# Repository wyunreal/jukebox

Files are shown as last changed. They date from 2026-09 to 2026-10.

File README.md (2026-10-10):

# jukebox

A homemade jukebox built around a **Raspberry Pi 4B** running
[Volumio](https://volumio.com/): firmware
for power control and input reading (potentiometers, switches and a 4x4 button
matrix) on **Arduino Micro (ATmega32U4)** boards, FreeCAD 3D models of the
hardware (screen, Raspberry Pi, HDD and electronics supports), the audio
software that gives the Pi a custom dual output, and the operations skill used
to run and troubleshoot the box.

## Status

The repository currently contains:

```
firmware/PowerAndPotsArduino/   # PlatformIO project (Arduino Micro)
├── src/main.cpp                # pot/switch reading and serial reporting
├── src/power-state-machine.hpp # relay + short/long press power switch logic
├── platformio.ini
└── README.md                   # detailed firmware documentation

firmware/KeyboardArduino/       # PlatformIO project (Arduino Micro)
├── src/main.cpp                # 4x4 button matrix scan and event reporting
├── platformio.ini
└── README.md                   # detailed firmware documentation

hardware/3d-models/             # FreeCAD models, grouped by part
├── Electronic support/         # PowerAndPots controller board, box, fuse case
├── hdd/                        # hard drive wall support
├── Pi support/                 # Raspberry Pi support
├── screen/                     # screen supports, cover and joints
└── Spectrum/                   # spectrum display frame

software/volumio/              # Volumio flavour (the live box)
├── dual-output/                # custom dual audio output for Volumio
│   ├── deploy.sh / uninstall.sh  # scripts: ship+run over SSH, thin uninstall
│   ├── files/                  # everything that lands on the Pi
│   │   ├── jukebox-audio.sh    # installer / verify / status (engine)
│   │   ├── camilladsp          # CamillaDSP v4.1.3 (armv7), tone-control engine
│   │   ├── libasound_module_pcm_cdsp.so  # cdsp ALSA plugin (armhf, patched)
│   │   ├── cdsp/               # plugin source (patched) + strrep.h
│   │   └── jukebox-audio-guard.* / 89-jukebox-audio.rules  # units + udev rule
│   └── README.md               # design doc: ALSA split, tone, variants, fail-safe
├── pot-overlay/                # on-screen indicator for balance/bass/treble
│   ├── install.sh / uninstall.sh / deploy.sh  # scripts
│   └── files/                  # everything that lands on the Pi
│       ├── jukebox-overlay.py  # dependency-free HTTP/SSE server (port 3210)
│       ├── overlay.js / overlay.css  # UI overlay (reuses Volumio's knob)
│       ├── apply.sh            # (re)inject the loader into the UI pages
│       └── uninject.py         # strip the loader on uninstall
├── ui-nav/                     # daemon -> UI screen navigation channel
│   ├── install.sh / uninstall.sh / deploy.sh  # scripts
│   └── files/                  # everything that lands on the Pi
│       ├── ui-nav.py           # dependency-free HTTP/SSE server (port 3211)
│       ├── ui-nav.js           # injected client; drives the UI's $state
│       ├── apply.sh            # (re)inject the loader into the UI pages
│       └── uninject.py         # strip the loader on uninstall
└── ui-boost/                   # touch UI performance kit for Volumio
    ├── install.sh / uninstall.sh / deploy.sh  # scripts
    └── files/                  # everything that lands on the Pi
        └── jukebox-ui.sh / jukebox-ui-guard.*  # helper + guard units

software/jukebox-pots/          # pot volume/balance/tone from the Arduino
├── install.sh / uninstall.sh / deploy.sh  # scripts
├── files/                      # everything that lands on the Pi
│   ├── jukebox-pots.py         # daemon: USB serial -> DAC volume/balance/tone
│   └── jukebox-pots.service / 89-jukebox-pots.rules / config.env.in
└── README.md                   # design doc: mapping, detection, analyser safety

software/jukebox-keyboard/      # playback keys from the KeyboardArduino
├── install.sh / uninstall.sh / deploy.sh  # scripts
├── files/                      # everything that lands on the Pi
│   ├── jukebox-keyboard.py     # daemon: USB serial -> play/pause/stop/prev/next
│   └── jukebox-keyboard.service / 89-jukebox-keyboard.rules / config.env.in
└── README.md                   # design doc: key map, detection

software/storage/               # host storage: RAID 1 music library
├── raid-music.sh               # set up / adopt the mirror + auto-mount (on-host)
└── README.md                   # design doc: power, UAS quirk, replacing a disk

skills/jukebox/SKILL.md         # agent skill to operate and troubleshoot the box
```

The audio setup splits playback into the I2S DAC (speakers, volume-controlled
by Volumio) and a second constant-level output feeding a hardware spectrum
analyser, with an automatic DAC-only fallback when the second device is absent.
The DAC branch also carries a live **bass/treble tone control** (CamillaDSP),
driven by two of the Arduino's potentiometers — see
[Installing from scratch](#installing-from-scratch).

## Physical controls

Four potentiometers of the PowerAndPots Arduino drive the DAC (speakers) only:

| Pot | Function |
| --- | --- |
| `POT volume` | Volumio volume (0–100 %) |
| `POT balance` | left/right balance of the DAC |
| `POT single` | bass shelf (±8 dB, center = flat) |
| `POT multi second` | treble shelf (±8 dB, center = flat) |

The spectrum analyser feed keeps its constant level and is not affected by any
of them (including the tone). See
[software/jukebox-pots/README.md](software/jukebox-pots/README.md).

## Firmware

- **Power relay** driven by a state machine: short press turns it on, short
  press while on asks the host to shut down (`POWER: soft off`), long press
  (≥ 5 s) performs an immediate hard off; the button acts on release. The relay
  is cut by the Arduino after the Pi has halted (see
  [Power button](software/jukebox-pots/README.md#power-button-soft-power-off)).
- **Serial reporting** (9600 baud, only on change): volume/single/balance/
  multi second pots (with per-segment calibration tables), power tristate,
  power switch, multi push and rotary switch.
- **Button matrix** (4x4, rows on 2-5, columns on 6-9): `DOWN`/`UP` on
  press/release, `PRESS` vs `LONG_PRESS` (1 s threshold) on release and a
  `PRESSED` repeat every 500 ms while held.

Pin map, output format, calibration and flashing: see
[firmware/PowerAndPotsArduino/README.md](firmware/PowerAndPotsArduino/README.md);
button matrix wiring and events: see
[firmware/KeyboardArduino/README.md](firmware/KeyboardArduino/README.md).

## 3D models

FreeCAD (`.FCStd`) models, grouped by part: see
[hardware/3d-models/README.md](hardware/3d-models/README.md).
No STL/STEP exports are committed yet — export from FreeCAD as needed.

## Audio software

Custom dual audio output (I2S DAC + constant-level second output for the
spectrum analyser) with a live bass/treble tone control, for **Volumio**.
Step-by-step, from scratch: see
[Installing from scratch](#installing-from-scratch).

See the full design doc:
[software/volumio/dual-output/README.md](software/volumio/dual-output/README.md)
(engine `files/jukebox-audio.sh`, shipped over SSH by `deploy.sh`).

Physical volume and balance from the PowerAndPots Arduino's potentiometers are
handled by `software/jukebox-pots/` (`jukebox-pots.service`): it reads `POT
volume` / `POT balance` / `POT single` / `POT multi second` over USB serial and
drives the DAC volume, balance and tone, leaving the analyser output untouched.
Install with `software/jukebox-pots/deploy.sh install`; see its
[README](software/jukebox-pots/README.md).

Moving a pot shows an on-screen indicator (a circular knob identical to
Volumio's own volume indicator) for **balance**, **bass** and **treble** — the
latter two are not part of Volumio's state, so `software/volumio/pot-overlay`
adds a small local SSE server that the daemon feeds and the UI renders; see its
[README](software/volumio/pot-overlay/README.md).

## Keyboard (playback keys)

The KeyboardArduino's 4x4 button matrix drives playback. `software/jukebox-keyboard/`
(`jukebox-keyboard.service`) reads its key events over USB serial and runs the
matching Volumio command on key **press**: play, pause, stop, previous track,
next track, mute, clear the queue and save the queue as a playlist. One key
toggles the current track/station in **favourites**, and one can **toggle the
screen** between the now-playing home and the play queue (those two ask the UI,
so they need `software/volumio/ui-nav`). The key → action map is **versioned in
the repo** at `software/jukebox-keyboard/files/keymap.conf` (`ACTION=row,col`) and
installed as-is, so a fresh or re-installed box gets the same keys (a one-off
`--key-action ACTION ROW,COL` overrides single entries). Identify a key with
`--watch`. Install with `software/jukebox-keyboard/deploy.sh install`; see its
[README](software/jukebox-keyboard/README.md).

## Disks & RAID 1 (music library)

The music library lives on **two 3.5" hard drives in USB enclosures, mirrored
(RAID 1)** and mounted where Volumio expects removable storage, so it isn't
capped by the SD card:

| | |
|---|---|
| Array | `/dev/md0`, `raid1`, name `<host>:music` |
| Mount | `/media` — what Volumio's `/mnt/USB` symlinks to, i.e. the **`USB`** source |
| Music | `/media/Music/` (SMB share **`USB`**) |

The set-up/adopt script and the full design notes (power requirements, the
JMicron JMS583 UAS workaround, replacing a failed disk) are in
[software/storage/](software/storage/README.md). From a development machine:

```sh
scp software/storage/raid-music.sh volumio@<host>:/tmp/
ssh volumio@<host> 'echo <password> | sudo -S -p "" \
  bash /tmp/raid-music.sh install --disk-a /dev/sda --disk-b /dev/sdb'
```

It is idempotent and safe: an existing array is only **adopted**, never
reformatted; a non-empty disk is **refused** unless `--reformat` is given.
`verify` / `status` check the array, the mount and the disks.

> **Power matters.** Two 3.5" drives cannot run off the USB bus, and a mirror
> writes to both at once. Without a proper power supply the drives brown out
> under load (USB disconnects, I/O errors, degraded array). These enclosures
> (`152d:0583`) are also unstable with the **UAS** driver, so `install` pins
> `usb-storage.quirks=152d:0583:u` to force Bulk-Only Transport.

## Adding music over the network (SMB)

Volumio already runs Samba (`smbd`/`nmbd`) with **guest** shares, so you don't
need to touch the box at all — just drag files onto it from your computer. The
Pi advertises itself on the LAN under **its own hostname**, so it shows up on its
own under the network neighbourhood / "Network" in your file manager.

### From the file manager (no password)

- **Windows / File Explorer** — open **Network**; the box appears there by
  itself (if it doesn't, type `\\<host>` — or `\\<pi-ip>` — in the address bar).
- **macOS / Finder** — **Go ▸ Connect to Server…** (`⌘K`) and enter
  `smb://<host>` (or `smb://<pi-ip>`).
- **Linux / GNOME Files (Nautilus)** — **Other Locations ▸ smb://<host>**.

| Share | What it is | Where it lands on the Pi |
|---|---|---|
| `Internal Storage` | the SD card: fine for a small library | `/data/INTERNAL` → `Music/` |
| `USB` | the RAID 1 music library (two mirrored HDDs) | `/mnt/USB` → `/media` |
| `NAS` | a staging area for files destined for a NAS | `/mnt/NAS` |

There is **no username or password** (the shares are `guest ok = yes`); connect
as guest/anonymous and open the share you want. For the music library use
**`USB`** and drop the files in its **`Music`** folder (or at the root), i.e.
`USB\Music\...`. The library shows every folder under the MPD music
root, so anything you place in there is indexed.

### From the command line

```sh
# Linux (mount the RAID music library at /mnt/jukebox)
sudo mkdir -p /mnt/jukebox
sudo mount -t cifs '//<host>/USB' /mnt/jukebox \
  -o guest,iocharset=utf8,file_mode=0777,dir_mode=0777
cp -r ~/Music/* /mnt/jukebox/Music/
sudo umount /mnt/jukebox

# macOS
open 'smb://<host>/USB'

# smbclient (guest, one-off copy)
smbclient '//<host>/USB' -N -c 'cd Music; lcd ~/Music; mput *'
```

For a small library you can use the SD card's `Internal Storage` share
(`//<host>/Internal Storage`, `Music/`) instead — the share name has a space,
so quote it.

### After copying: re-scan the library

Volumio's MPD watches its folders but a full (re)scan is the reliable way to
make new files appear. In the web UI: **Browse ▸ My Music ▸ Update** (or
Settings ▸ Sources). The button posts MPD's database update, and from the
command line `mpc` talks to the same daemon:

```sh
mpc update      # incremental: pick up new/changed files
mpc rescan      # full re-read of the whole library
```

> Volumio's REST API does **not** expose `updateLibrary`/`rescan` (the UI uses a
> socket), so `curl '.../api/v1/commands/?cmd=updateLibrary'` answers *command
> not recognized* — use `mpc`, the UI button, or just wait for MPD to notice.
> A file only becomes playable once MPD has it in its database, so if the UI
> lists the file but playback fails or it's missing, run `mpc update`.

## Installing from scratch

Everything below runs from a **development machine** (this repo) and drives the
Pi over SSH. Nothing is hardcoded: pass the host (and a password if you don't
use SSH keys) per command.

Requirements:

* A Raspberry Pi with the I2S DAC (PCM1794A, `sndrpirpidac`) and, for the
  analyser, a USB sound card (`Device`).
* The **PowerAndPots Arduino** flashed
  ([firmware/PowerAndPotsArduino](firmware/PowerAndPotsArduino/README.md)) and
  plugged in (it appears as `/dev/ttyACM0`).
* SSH enabled on the Pi. Either an SSH key or the `-p/--password` option (the
  password is also needed for `sudo` unless it is passwordless).

The order matters: **player first, then the audio chain, then the pots.**

There is also a top-level wrapper that drives all six packages in that order:

```sh
./deploy-all.sh -H user@host install     # every package; second output = usb
./deploy-all.sh -H user@host verify      # run every package's checks
./deploy-all.sh -H user@host status      # show every package's state
./deploy-all.sh -H user@host uninstall   # remove every package (reverse order)
```

The host is **required**: pass `-H/--host user@host` or set `JUKEBOX_HOST`
(there is no built-in default). Use `-p <password>` (or `$JUKEBOX_PASSWORD`) when
`sudo` on the box needs one:

```sh
./deploy-all.sh -H volumio@<host> -p <pass> install
./deploy-all.sh -H volumio@<host> status
```

It just sequences each package's own `deploy.sh`, so the per-package steps below
are the same thing done by hand (and are still the way to pass package-specific
options such as `--key-action`). For this box, `install` fixes the second output
to `usb`. The pot power button (short press halts the Pi) is on by default;
disable it per package with `--no-power-button`:

```sh
# one package at a time (same effect as the orchestrator, with its own flags)
software/volumio/dual-output/deploy.sh  -H volumio@<host> -p <pass> install --second-output usb
software/volumio/ui-boost/deploy.sh     -H volumio@<host> -p <pass> install
software/jukebox-pots/deploy.sh         -H volumio@<host> -p <pass> install --power-off-delay 45
software/volumio/pot-overlay/deploy.sh  -H volumio@<host> -p <pass> install
software/volumio/ui-nav/deploy.sh       -H volumio@<host> -p <pass> install
software/jukebox-keyboard/deploy.sh     -H volumio@<host> -p <pass> install --key-action next 1,4
```

### Volumio (the live box)

1. Flash Volumio and finish its first-run wizard (network, audio output).
   Note the host and the `volumio` user's password.

2. Install the dual output + tone (DAC branch + constant-level USB analyser;
   the tone engine CamillaDSP and the patched `cdsp` plugin are shipped by this
   repo):

   ```sh
   cd software/volumio/dual-output
   ./deploy.sh --host volumio@<host> install --second-output usb
   ```

   Add `--with-playback` to also run the playback check. On a Volumio box the
   installer configures the ALSA split, the MPD buffers, the guard units and
   the CamillaDSP tone step, and ends with a verification table that must say
   **All checks passed**.

3. Install the potentiometer daemon (volume, balance, bass, treble). The pot
   power button (short press halts the Pi, relay cut ~30 s later) is on by
   default; `--no-power-button` / `--power-off-delay N` change that:

   ```sh
   cd software/jukebox-pots
   ./deploy.sh --host volumio@<host> install                       # power button on, 30 s
   ./deploy.sh --host volumio@<host> install --no-power-button     # short press does nothing
   ./deploy.sh --host volumio@<host> install --power-off-delay 45  # cut the relay after 45 s
   ```

   Then, for the on-screen indicator when moving balance/bass/treble pots:

   ```sh
   cd software/volumio/pot-overlay
   ./deploy.sh --host volumio@<host> install
   ```

4. *(Optional)* Speed up the touch UI (GPU compositing, no blur, correct DSI
   resolution):

   ```sh
   cd software/volumio/ui-boost
   ./deploy.sh --host volumio@<host> install
   ./deploy.sh --host volumio@<host> status
   ```

   It takes full effect after a reboot (`ssh volumio@<host> 'sudo reboot'`).

5. *(Optional)* Wire the keyboard's playback keys. The map is versioned in
   `software/jukebox-keyboard/files/keymap.conf`; install it as-is (identify a
   key with `--watch` and edit the file if needed):

   ```sh
   cd software/jukebox-keyboard
   ./deploy.sh --host volumio@<host> install
   ```

   A one-off `--key-action ACTION ROW,COL` (repeatable) overrides single entries
   without touching the repo.

6. **Reboot** so `alsa-restore`, the guard units and the pot daemon come up
   together, then play something and move the four pots.

Verification / state any time (all packages at once, or a single one):

```sh
./deploy-all.sh -H volumio@<host> verify                # every package
./deploy-all.sh -H volumio@<host> status                # every package
./software/volumio/dual-output/deploy.sh --host volumio@<host> verify --with-playback
./software/jukebox-pots/deploy.sh --host volumio@<host> status
```

If `sudo` on the box needs a password, add `-p <password>` or export
`JUKEBOX_PASSWORD=<password>`.

### What each installer does

| Package | What it installs |
|---|---|
| `software/volumio/dual-output` | ALSA split + CamillaDSP tone step + guards + MPD buffers for Volumio |
| `software/volumio/pot-overlay` | On-screen balance/bass/treble indicator (overlay server + injected UI loader) |
| `software/volumio/ui-nav` | UI navigation channel (a daemon can switch the screen; used by the open/close key) |
| `software/jukebox-pots` | `jukebox-pots.service` (volume/balance/tone from the Arduino; power button halts the Pi, on by default) |
| `software/jukebox-keyboard` | `jukebox-keyboard.service` (play/pause/stop/prev/next/mute/clear/save-queue, favourite, open/close the queue view) |
| `software/volumio/ui-boost` | Volumio-only touch UI performance fixes |

## Safety notice

This project drives a power relay (low-voltage control side) and includes
parts meant to be printed and assembled with electronic and electrical
components. In this build the relay switches a PC **ATX power supply**, so the
relay contacts are low voltage — but the PSU still has mains at its input, and
an ATX supply carries high currents and stored energy. Handle it with the usual
care for electrical work; a supply can still get hot or hold a charge. None of
it is a certified or safety-rated design. Use it entirely at your own risk;
if you are not comfortable working with electronics or mains wiring, don't —
consult a professional.

## License

MIT, plus an additional disclaimer of liability and safety notice — see
[LICENSE](LICENSE). The project is provided "as is", with no warranty and no
responsibility for any damage or injury arising from its use.

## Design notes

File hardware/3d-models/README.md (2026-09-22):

# 3D models

FreeCAD models (`.FCStd`) of the jukebox hardware, grouped by part.
Files were made with FreeCAD 1.0 / 1.1 — open with FreeCAD ≥ 1.0.

## Printing

No STL/STEP exports are committed yet — export from FreeCAD
(`File → Export`) and slice as needed.

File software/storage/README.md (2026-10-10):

# storage — RAID 1 music library

Two 3.5" SATA hard drives in USB enclosures, mirrored (**RAID 1**) and mounted
where Volumio expects removable storage, so the music library lives on the
disks instead of the SD card. This directory is **not a package** (no
`deploy.sh` / `install.sh`): it is the on-host script plus this doc. Run it by
hand over SSH.

## What it does

| | |
|---|---|
| Array | `/dev/md0`, `raid1`, name `<host>:music` (so `/dev/md/music`) |
| Filesystem | `ext4`, label `MUSIC` |
| Mount | `/media` — which is what Volumio's `/mnt/USB` symlinks to, so the library shows it as the **`USB`** source |
| Music goes in | `/media/Music/` (SMB share **`USB`**, or `Internal Storage` stays on the SD) |
| Boot | assembled by the `mdadm` udev rules (`/etc/mdadm/mdadm.conf`) and mounted from `/etc/fstab`; the `raid1`/`md_mod` modules are pinned in `/etc/modules-load.d/raid.conf` |

## The important hardware caveats

1. **The disks need their own power supply.** A 3.5" drive needs 12 V + 5 V and
   draws several watts; the USB bus (5 V, 0.5 A) cannot run one, let alone two.
   And a mirror **writes to both disks at once**, so a RAID 1 doubles the power
   draw. Without a proper PSU (the enclosure/dock's barrel jack, or a
   self-powered hub) the drives brown out under load: USB disconnects, I/O
   errors and a quickly-degraded array. This is the number one failure mode.
2. **These enclosures (JMicron JMS583, `152d:0583`) are unstable with UAS.**
   Under load they drop off the bus. The script pins
   `usb-storage.quirks=152d:0583:u` in `/boot/cmdline.txt` to force Bulk-Only
   Transport (`usb-storage`) instead of UAS. It's applied from the next boot.
3. **Watch the negotiated speed.** Some of these adapters report themselves as
   USB 2.0 (`bcdUSB 2.10`) and will never exceed 480 Mbps, however blue the port
   is. ~15–30 MB/s is plenty for playback; it only hurts large copies. If you
   want USB 3.0 speeds, use real USB 3.0 enclosures.

Volumio's root is an overlay on the SD card, so `/etc` changes persist across
reboots — but a **Volumio system update** can reset `/boot/cmdline.txt`, taking
the UAS quirk with it (and the cuelgues come back). Re-run `install` after an
update. The array and its data live on the physical disks and survive anything
done to the SD card.

## Usage (on the Volumio host, as root)

```sh
sudo ./raid-music.sh install                       # create (or adopt) + mount
sudo ./raid-music.sh install --disk-a /dev/sda --disk-b /dev/sdb
sudo ./raid-music.sh install --reformat            # allow wiping non-empty disks
sudo ./raid-music.sh install --resync              # force a full initial resync
sudo ./raid-music.sh install --no-quirk            # don't touch /boot/cmdline.txt
sudo ./raid-music.sh apply                         # re-assert config + mount (idempotent)
sudo ./raid-music.sh verify                        # pass/fail checks
sudo ./raid-music.sh status                        # array, mount, disks, SMART
sudo ./raid-music.sh uninstall                     # remove config, keep the data
sudo ./raid-music.sh uninstall --wipe              # DESTROY the array and its data
```

Safety model:

* If the array already exists it is **adopted** — only `mdadm.conf`, `fstab` and
  the mount are re-asserted. Never reformatted.
* With no array, it uses **two empty whole disks** (auto-detected, or given with
  `--disk-a/--disk-b`). A disk with a partition table or a filesystem is
  **refused** unless `--reformat` is passed.

### From the development machine

```sh
scp software/storage/raid-music.sh volumio@<host>:/tmp/
ssh volumio@<host> 'echo <password> | sudo -S -p "" \
  bash /tmp/raid-music.sh install --disk-a /dev/sda --disk-b /dev/sdb'
```

## Replacing a failed disk

The array keeps serving in degraded mode. To re-add a disk, find the device by
serial and add it; `mdadm` rebuilds the mirror (slow over USB 2.0):

```sh
ls -l /dev/disk/by-id/ata-*                       # find the replacement
sudo mdadm /dev/md0 --add /dev/sdX
watch -n2 cat /proc/mdstat                       # wait for [2/2] [UU]
```

## Recovery

```sh
cat /proc/mdstat
sudo mdadm --detail /dev/md0
sudo ./raid-music.sh verify
dmesg | grep -iE 'usb|uas|I/O error|reset'       # link problems live here
```

If both disks vanish, it's almost always power or the USB link, not the disks —
check the PSU and the enclosure before touching the array.

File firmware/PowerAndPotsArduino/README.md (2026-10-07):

# PowerAndPotsArduino

Firmware for the jukebox's **Arduino Micro (ATmega32U4)**: drives the power
relay through a power switch state machine and reports the state of
potentiometers and switches over USB serial (9600 baud).

## Power switch state machine (`src/power-state-machine.hpp`)

The relay starts **OFF** when the Arduino powers up. All turn-on actions
happen **on button release**:

| Relay state | Press | Action |
|---|---|---|
| OFF | short or long (any) | on release: relay **ON** + `POWER: ON` |
| ON | short (< 5 s) | on release: `POWER: soft off` (relay stays on) |
| ON | long (≥ 5 s) | at 5 s, while still held: `POWER: hard off` + relay **OFF** immediately (the later release is ignored) |

The long-press threshold lives in `POWER_LONG_PRESS_MS` (5000 ms).

### Soft off → the host powers itself down

`POWER: soft off` is a *request*, not an action: the host (the Raspberry Pi)
turns it into a clean shutdown. The **jukebox-pots** daemon watches for that
line and, when the power button is enabled, powers the Pi off and tells this
board to cut the relay **afterwards**:

```
button short press --> POWER: soft off --> Pi: systemctl poweroff
                                      \-> "POWER: off 30" --> relay OFF in 30 s
```

The relay must stay on while the Pi halts, and the Pi cannot send anything once
it is down — but this board keeps running from 5VSB — so the **delay lives
here**. On `POWER: off [N]` the firmware arms a cut `POWER_OFF_DELAY_MS`
(default 30000 ms) later; the optional `N` (seconds, may be `0`) overrides it,
so the host can tune the delay without reflashing. The cut prints
`POWER: hard off` when it happens. A **long press** still cuts immediately and
cancels any pending cut (`POWER: off cancelled`), which is also the escape
hatch if the Pi hangs and never shuts down.

> A second short press after the Pi has halted re-turns the relay on
> (`POWER: ON`) without booting anything, because the Pi is down. Use the long
> press to cut cleanly.

## Serial report

Output over USB at 9600 baud. Values are only reported when they change,
at most every 250 ms (`REPORT_INTERVAL_MS`). A `-----` separator is printed
whenever anything is reported.

**Status request.** Send a newline (or any line that does not start with
`POWER:`) and the firmware re-emits every value once, even if none changed. The
host uses this right after opening the port (`jukebox-pots` writes a newline) so
it can seed the volume and balance from the current pot positions — needed
because the board may already be running (powered from 5VSB) when the Pi boots
and would otherwise stay silent.

**Host commands.** A line beginning with `POWER:` is a command instead of a
status request (the line ends at `\n`/`\r`):

| Line from the host | Effect |
|---|---|
| `POWER: off` | arm a relay cut after `POWER_OFF_DELAY_MS` (30 s) |
| `POWER: off N` | same, but cut after `N` seconds (may be `0`) |
| `POWER: cancel` | disarm a pending cut (host could not shut down) |

Any other input (including a lone newline) is the full status request above.

```
POT volume: 15 (raw 700)
POT single: 20 (raw 1020)
POT balance: 10 (raw 512)
POT multi second: 0 (raw 540)
POT aux: 12 (raw 640)
POWER tristate: CENTER|LEFT|RIGHT
POWER switch: ON|OFF
MULTI PUSH switch: ON|OFF
MULTI ROTARY switch: OFF|SW1|SW2
-----------------------------------------
```

Potentiometers are scaled through per-segment calibration tables
(`POT_VOLUME_POINTS`, `POT_SINGLE_POINTS`, `POT_BALANCE_POINTS`,
`POT_MULTI_SECOND_POINTS`, `POT_AUX_POINTS` in `src/main.cpp`): each entry maps
a raw reading to a value, interpolating between points. Adjust them there to
calibrate your hardware.

## Multiplexer

The Pro Micro only breaks out A0-A3 and all four are used, so extra pots go
through a **CD4051B** 8:1 analog mux whose common output feeds `A0`. Address
bits (C tied to GND; `INH` and `VEE` to GND):

| A (D7) | B (D5) | Channel | Pin | Pot |
|---|---|---|---|---|
| 0 | 0 | X0 | 13 | multi second |
| 1 | 0 | X1 | 14 | balance |
| 0 | 1 | X2 | 15 | **aux** (spare) |
| 1 | 1 | X3 | 12 | spare |

The firmware reads the three channels in turn each loop by setting A
(`MUX_SELECT_PIN`) and B (`MUX_SELECT2_PIN`). To add a fourth pot, wire the next
channel to a free mux input and add its read (with a `PotPoint` table and a
`ReportedValue`) in the same block.

## USB identification

The jukebox also carries a KeyboardArduino; both are identical Arduino Micros
(same VID:PID, no unique USB serial). To let the host tell them apart without
depending on which USB port each is plugged into, this firmware sets
`board_build.usb_product = Jukebox Pots` in `platformio.ini`, so the board
enumerates with the product string **"Jukebox Pots"** (and appears as
`/dev/serial/by-id/usb-Jukebox_Pots_*-if00`). The keyboard board sets its own
string. `jukebox-pots` selects the port by this string.

## Pin map

| Pin | Function | Notes |
|---|---|---|
| 2 | Power relay | **active-low** module (`RELAY_ON = LOW`), defined in `power-state-machine.hpp` |
| 14 | Power switch | `INPUT`, HIGH = pressed |
| 15 | Single pot supply | enabled only during its reading |
| A0 | Mux analog input | |
| 7 | Mux address A | LOW = multi second pot, HIGH = balance pot |
| 5 | Mux address B | LOW = X0/X1, HIGH = X2 aux pot (see above) |
| A1 | Volume pot | |
| A2 | Power tristate pot | raw > 500 → RIGHT, > 100 → LEFT, else CENTER |
| A3 | Single pot | |
| 4 | Multi push switch | `INPUT_PULLUP`, active LOW (ON = pressed) |
| 8, 9 | Rotary switch 1/2 | `INPUT_PULLUP`, active LOW |

## Build and flash

[PlatformIO](https://platformio.org/) project:

```sh
pio run                # build
pio run -t upload      # flash
pio device monitor     # serial monitor (9600)
```

On Linux, install the udev rules so the Micro's port is accessible
without root:

```sh
sudo cp 99-platformio-udev.rules /etc/udev/rules.d/
sudo udevadm control --reload-rules && sudo udevadm trigger
```

`99-platformio-udev.rules` is PlatformIO's standard file (Apache 2.0).

## Layout

```
src/main.cpp                  # pot/switch reading and serial reporting
src/power-state-machine.hpp   # relay + short/long press power switch logic
99-platformio-udev.rules      # PlatformIO udev rules (Linux)
```

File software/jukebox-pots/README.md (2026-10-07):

# jukebox pots (volume + balance + tone from the Arduino)

Turns four potentiometers of the **PowerAndPotsArduino** into physical
controls **for the speakers (I2S DAC) only**: volume, balance, bass and
treble.

The Arduino prints their state on its USB serial port (9600 baud, only on
change):

```
POT volume: 15 (raw 700)
POT balance: 10 (raw 512)
POT single: 12 (raw 640)
POT multi second: 8 (raw 430)
POT aux: 18 (raw 900)
POWER switch: ON
```

The Arduino also reports its power button (`POWER: soft off` on a short press,
`POWER: hard off` on a long one); the daemon can turn that into a clean Pi
shutdown — see [Power button](#power-button-soft-power-off).

A small daemon reads those lines and applies them to the DAC branch of the
chain, on the **Volumio** box:

| Pot | Range | Effect |
| --- | --- | --- |
| `POT volume` | 0–20 | Volumio volume ceiling, 0–100 % |
| `POT aux` | 0–20, 20 = full | **auxiliary volume**: attenuates the ceiling, 0 = silence |
| `POT balance` | 0–20, center 10 | pan of the DAC left/right (opposite channel attenuated) |
| `POT single` | 0–20, center 10 | **bass** shelf, ±8 dB |
| `POT multi second` | 0–20, center 10 | **treble** shelf, ±8 dB |

The two volume pots **multiply**: the volume pot sets the system ceiling and
the aux pot scales it down. The value sent to the player is
`volume_pot × (aux / 20)`, so the aux never exceeds the ceiling and reaches
silence at 0:

| `POT volume` | `POT aux` | Volumio |
| --- | --- | --- |
| 20 (100 %) | 20 | 100 % |
| 20 (100 %) | 10 | 50 % |
| 10 (50 %) | 20 | 50 % |
| 10 (50 %) | 10 | 25 % |
| 20 (100 %) | 0 | 0 % (silence) |

Both are re-applied whenever either pot moves. Older firmware without the
`POT aux` line still works: the aux then defaults to full.

Center (10) on either tone pot means **0 dB**, i.e. bit-for-bit transparent.
The pots are not hard-wired to a function: `JP_TONE_BASS_POT` and
`JP_TONE_TREBLE_POT` pick which firmware lines drive bass and treble
(`single` / `multisecond` by default).

The **second, constant-level output that feeds the spectrum analyser is never
touched**: volume lives on the DAC branch only and the tone shelves live on the
DAC branch only, so nothing in this package can change its level or response.

## How it works

```
PowerAndPotsArduino --USB serial--> jukebox-pots daemon
                                      | volume  -> player volume (DAC branch)
                                      | balance -> DAC pan (per-channel)
                                      '- tone    -> CamillaDSP config + SIGHUP (live)
```

The volume path, balance and tone are those of the **Volumio** chain:

| | Volumio |
| --- | --- |
| Volume | Volumio API (`/api/v1/commands/?cmd=volume`) -> `SoftMaster` |
| Balance | two channels of `SoftMaster Playback Volume` |
| Tone | shelves in `/usr/local/jukebox-audio/cdsp/camilla.*.yml` |

* **Volume** goes through Volumio's own volume path, so the UI/API stay in
  sync, and is the product of the volume pot (ceiling) and the aux pot
  (attenuation). If the API is unreachable the daemon writes the ALSA mixer
  directly instead.
* **Balance** attenuates the channel opposite to the pan, keeping the other at
  its current level via the left/right values of `SoftMaster`.
* **Bass/treble** rewrite the two shelf `gain:` values in the CamillaDSP
  config and send the running process a `SIGHUP`; it re-reads the config and
  rebuilds the filters **without interrupting playback**. The rewrite finds
  the shelves by their biquad type (`Lowshelf`/`Highshelf`) and preserves the
  file's mode/owner so MPD's `cdsp` plugin can keep rewriting it.
* The daemon has **no third-party dependencies** (no `pyserial`); it opens the
  serial port with `termios` and re-scans for it when missing, so it survives
  the Arduino being unplugged/replugged. A udev rule also restarts it when a
  `ttyACM`/`ttyUSB` appears.
* Right after opening the port the daemon **requests a full status report** (it
  writes one byte; the firmware re-emits every value). This is required at boot:
  the board is powered from 5VSB and may already be running when the Pi comes
  up, and the firmware only reports on change, so without the request the daemon
  would never learn the current pot positions and volume/balance would not be
  seeded.
* The daemon never asserts DTR (see the clone notes above); the firmware reports
  regardless of it, and the status request is a plain byte.

## Power button (soft power off)

The PowerAndPots Arduino runs the board's power state machine, so its button is
the jukebox's power button. A **short press** prints `POWER: soft off` and
leaves the relay on; a **long press** (≥ 5 s) cuts the relay immediately.

With the power button enabled (the default), the daemon turns that short press
into a clean shutdown of the Pi:

```
button short press --> Arduino "POWER: soft off"
                   --> daemon: send "POWER: off 30" to the Arduino
                   --> daemon: systemctl poweroff
                   --> Arduino waits 30 s, then cuts the power relay
```

The relay must stay on until the Pi has finished halting, and the Pi cannot
send anything once it is down. The board, however, keeps running from 5VSB, so
the **delay lives there**: the daemon arms it in the last message it sends
(`POWER: off <delay>`), the firmware counts down and cuts the relay. The delay
is `--power-off-delay` / `JP_POWER_OFF_DELAY_S` (**default 30 s**, choose your
own margin for how long the Pi really takes to halt). The **long press** stays
the immediate hard cut, and cancels any pending cut — the escape hatch if the
Pi hangs.

This is **on by default**; it is irreversible: once the Pi is down, software
cannot bring it back. Disable it with `--no-power-button` (or
`JP_POWER_BUTTON=0`). `--power-cmd "CMD"` overrides the halt command (default
`systemctl poweroff`); the daemon runs as root. Inspect the sequence without
touching anything with:

```sh
sudo /usr/local/jukebox-pots/jukebox-pots.py --poweroff-test
```

> The daemon must not assert DTR (see the DTR note above): it reboots the board,
> which resets the relay and would drop power. Nothing here does.

## Install

From this directory (the script copies itself to the Pi and runs it there):

```sh
./deploy.sh install
```

Or directly on the host (Volumio):

```sh
sudo ./install.sh install
```

Common option examples (all flags are also in the table below):

```sh
./deploy.sh install                              # power button ON, relay cut 30 s after
./deploy.sh install --no-power-button            # short press does nothing
./deploy.sh install --power-off-delay 45         # wait 45 s before cutting the relay
./deploy.sh install --power-cmd 'shutdown -h now'
```

The installer is **idempotent**: re-running it just re-asserts the same files
and restarts the service. It will:

1. detect the I2S DAC card (`sndrpirpidac`) unless `--dac-card` is given,
2. install the daemon in `/usr/local/jukebox-pots/`,
3. install and enable `jukebox-pots.service` (starts at boot, stays up,
   `Restart=always`),
4. install a udev rule that restarts the service when the serial port appears.

## Verify / operate

```sh
./deploy.sh status
./deploy.sh verify
./deploy.sh uninstall
```

* `status` shows the detected port, its USB product string and the current
  `SoftMaster` Left/Right values.
* `verify` checks the daemon, the self-tests, the unit state, the serial port
  and the `SoftMaster` control.
* The daemon can be probed on its own:

  ```sh
  sudo /usr/local/jukebox-pots/jukebox-pots.py --probe    # port + mixer + a few lines
  sudo /usr/local/jukebox-pots/jukebox-pots.py --selftest # mapping tests
  ```

## Identify the Arduino

The jukebox has **two identical Arduino Micros** (the PowerAndPots one and the
keyboard one). They share the USB VID:PID `2341:8037` and carry **no unique USB
serial number**, so the kernel cannot tell them apart by id — and binding the
daemon to a port number or a `by-path` link would break as soon as a cable or
hub moved. Instead each board is flashed with its own **USB product string**:

| Board | `board_build.usb_product` | `/dev/serial/by-id` link |
| --- | --- | --- |
| PowerAndPots | `Jukebox Pots` | `usb-Jukebox_Pots_*-if00` |
| Keyboard | `Jukebox Keyboard` | `usb-Jukebox_Keyboard_*-if00` |

The daemon selects the board whose product string is `Jukebox Pots`
(`--product` / `JP_PRODUCT` to change it, must match the firmware). Lookup
order:

1. `--port DEV` / `JP_PORT` if you set one explicitly;
2. a `/dev/serial/by-id/*` symlink whose name matches the product string;
3. any `/dev/ttyACM*` / `/dev/ttyUSB*` whose sysfs `product` matches.

> If `lsusb` does not show the board at all, it is usually a **charge-only USB
> cable** or a port without data lines. Try another cable before anything else.

### Powering the board from 5VSB (VBUS sense)

On the ATmega32U4 the **VBUS pin is not only power — it is the "a USB host is
present" signal**. The chip only talks USB when it sees ~5 V there.

Feeding 5VSB into the Arduino **`5V` pin** is fine and, on a genuine Arduino
Micro, *also* satisfies VBUS: its power-select FET (T1) connects `5V` to the
VUSB net whenever VIN is low, so the 5 V also reaches the VBUS sense input. The
usual cable with the **VBUS wire cut** (D+/D-/GND only) then has no path back to
the Pi, so there is no back-feed either.

* VBUS cut + 5 V into `5V` (Micro) -> sense OK, enumerates, no back-feed.
* VBUS intact + 5 V into `5V` -> works, but 5VSB can push ~150 mA back into the
  Pi's USB port through T1 + the polyfuse; put a Schottky in the VBUS wire
  (cathode towards the Arduino) if you keep the cable whole.

**Clone warning (e.g. Pro Micro).** The clones have no T1, so feeding their `5V`
/ `VCC` pin does **not** put anything on VBUS sense: the board is powered (LEDs
on) but **never enumerates** — `lsusb` stays empty and `dmesg` shows no attempt
at all. The fix is to tie the supply to VBUS sense:

* bridge the **`J1`/`SJ1` solder jumper** (present on the Pro Micro, next to the
  USB connector) — its one pad is VCC and the other is UVCC/VBUS. On a 5 V board
  it is meant to be closed; or
* solder a wire from the `5V`/`VCC` pin to the VBUS net (the USB-C VBUS pins
  A4/A9/B4/B9, or the polyfuse `F1` beside the connector).

Measure to confirm: with 5VSB on and **no USB cable**, the VBUS net must read
~5 V. Then the board appears as `2341:8037` on `/dev/ttyACM0` within a second or
two of the Pi's USB becoming active.

### DTR resets the board (and the power relay)

The daemon deliberately **does not assert DTR**. On the Arduino Micro DTR is
wired to reset, and this board also runs the power-button state machine: raising
DTR reboots it, which resets the relay state and would cut power if the jukebox
is running. The firmware streams regardless of DTR, so plain `termios` suffices.

## Options

| Option | Default | Meaning |
| --- | --- | --- |
| `--dac-card NAME` | auto | ALSA card id of the DAC |
| `--port DEV` | auto | serial device (overrides product matching) |
| `--product STR` | `Jukebox Pots` | USB product string of the PowerAndPots board |
| `--baud N` | 9600 | serial baud rate |
| `--pot-max N` | 20 | firmware pot range |
| `--volume-max N` | 100 | player volume scale |
| `--balance-center N` | 10 | pot value meaning "centered" |
| `--balance-span N` | 10 | pot steps from center to hard pan |
| `--volume-invert` | off | reverse the volume pot direction |
| `--balance-invert` | off | reverse left/right |
| `--no-api` | off | write the mixer directly instead of the player volume path |
| `--tone` / `--no-tone` | on | enable/disable the bass+treble pots |
| `--tone-max-db N` | 8 | shelf range at the pot extremes |
| `--tone-center N` | 10 | pot value meaning "flat" |
| `--tone-span N` | 10 | pot steps from center to full shelf |
| `--tone-bass-pot NAME` | single | firmware line driving bass (`single`/`multisecond`) |
| `--tone-treble-pot NAME` | multisecond | firmware line driving treble |
| `--tone-bass-invert` | off | reverse the bass pot direction |
| `--tone-treble-invert` | off | reverse the treble pot direction |
| `--power-button` / `--no-power-button` | on | short power-button press halts the Pi |
| `--power-off-delay N` | 30 | seconds the Arduino waits before cutting the relay |
| `--power-cmd CMD` | `systemctl poweroff` | command used to halt the Pi |

The same values can be set as environment variables in
`/usr/local/jukebox-pots/config.env` (`JP_*`), which the unit loads at start.

## Notes

* The firmware already scales the raw ADC reading, so the daemon consumes the
  `POT volume` / `POT balance` / `POT single` / `POT multi second` values
  directly. If you re-calibrate the pots in the firmware, the daemon needs no
  change.
* `SoftMaster` is created by the `softvol` plugin the first time the chain is
  opened. The daemon creates it on demand (a 1-second silent `aplay`) if it is
  missing, and the standard `jukebox-audio` install materializes it too.
* Balance is relative to the current level, so it keeps working across volume
  changes; only the two channel values of `SoftMaster` are written.
* The tone pots only work when the dual-output package was installed with the
  tone enabled (the default). Gains are applied live with a `SIGHUP` on
  `/usr/local/jukebox-audio/cdsp/`; the template is updated too, so the
  setting survives a regeneration by the guard and a reboot.
* The daemon never asserts DTR (see the hardware notes above); the firmware
  reports regardless of it, and the status request is a plain byte.
* Uninstall removes the service, the unit, the udev rule and
  `/usr/local/jukebox-pots/`, and restores nothing else — the audio chain was
  never modified by this package.

## Layout

```
install.sh            # idempotent installer (install/verify/status)
uninstall.sh          # remove the service, unit, udev rule and files
deploy.sh             # ship and run install.sh/uninstall.sh over SSH
files/                # everything that lands on the host (readable, human)
├── jukebox-pots.py   # the daemon (+ --probe and --selftest)
├── jukebox-pots.service
├── 89-jukebox-pots.rules
└── config.env.in     # settings template (@PLACEHOLDER@ filled at install)
README.md             # this file
```

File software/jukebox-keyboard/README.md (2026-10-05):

# jukebox keyboard (playback keys)

Turns the **KeyboardArduino** (a 4x4 button matrix) into playback transport
controls for the jukebox: play, pause, stop, previous track and next track.

The board reports key events over USB serial (9600 baud, `<EVENT> <row> <col>`,
1-based). A small daemon reads them and runs the matching Volumio command, so
pressing a key acts immediately (`DOWN` / `on key press`).

It finds its board the same way as `jukebox-pots`: by the **USB product string**
baked into the firmware (`board_build.usb_product = Jukebox Keyboard`), never by
USB port. The two Arduino Micros are identical, so the port would not be stable.

## Layout

```
install.sh             # installer / verify / status
uninstall.sh           # remove the service, unit, udev rule and files
deploy.sh              # ship and run install.sh/uninstall.sh over SSH
files/                 # everything that lands on the host (readable, human)
├── jukebox-keyboard.py
├── jukebox-keyboard.service
├── 89-jukebox-keyboard.rules
├── keymap.conf        # the key map (source of truth: ACTION=ROW,COL)
└── config.env.in      # settings template; keymap.conf fills the key map (@PLACEHOLDER@)
README.md
```

Favourite and the open/close screen toggle are not Volumio commands: the daemon
asks the UI to do them (via `software/volumio/ui-nav`), so the UI updates itself
(heart, toast, routing). Everything else runs the Volumio API directly.

## Configuration

The key -> action map is **versioned in the repo** at
`software/jukebox-keyboard/files/keymap.conf` (`ACTION=ROW,COL`, 1-based, one per
line). `install.sh` installs it as `/usr/local/jukebox-keyboard/config.env`, so a
fresh box (or a re-install) gets exactly the map in the repo. Edit `keymap.conf`
and re-run the installer to change it; a one-off `--key-action ACTION ROW,COL`
on the command line overrides a single entry for that run.

Actions:

| Action | Volumio command |
|---|---|
| `PLAY` | `cmd=play` |
| `PAUSE` | `cmd=pause` |
| `STOP` | `cmd=stop` |
| `CLEAR` | `cmd=clearQueue` (empties the play queue) |
| `PREV` | `cmd=prev` |
| `NEXT` | `cmd=next` |
| `MUTE` | toggles mute (reads the current state, then mute/unmute) |
| `OPENCLOSE` | toggles the UI between the now-playing home and the play queue |
| `FAVOURITE` | toggles the current track/station in favourites (music uses Volumio's own path; radios are handled by `ui-nav`, see below) |
| `SAVEQUEUE` | saves the current queue as a playlist, auto-named `Playlist N` (asks `ui-nav` for the next free name) |

`FAVOURITE` runs through the UI (`software/volumio/ui-nav`), so the heart and
the toast update. For **webradio** this is not just cosmetic: Volumio's backend
has a gap (its `checkFavourites` only looks at the music favourites list), so
its own heart never lights for a radio and its add never toggles. `ui-nav` fills
that in for radios only.

`OPENCLOSE` is not a Volumio command: it asks the UI to switch view, so it needs
`software/volumio/ui-nav` installed (its server is the daemon → UI channel, and
its injected client calls the UI's `$state`).

## Identify the keys

The board prints `DOWN r c` on press, `UP r c` on release and `PRESS r c` /
`LONG_PRESS r c` on release as a classification. To find a key's coordinates,
watch the port and press it:

```sh
sudo /usr/local/jukebox-keyboard/jukebox-keyboard.py --probe
# or watch live:
sudo /usr/local/jukebox-keyboard/jukebox-keyboard.py --watch
```

## Install

```sh
./deploy.sh --host volumio@<host> install
```

The key map comes from `files/keymap.conf`; `--key-action ACTION ROW,COL`
(repeatable) overrides single entries for a one-off run.

The overlay/UI packages are independent; this one only needs the keyboard board
flashed with its own USB product string.

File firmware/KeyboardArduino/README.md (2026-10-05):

# KeyboardArduino

Firmware for the jukebox's **Arduino Micro (ATmega32U4)**: scans a 4x4
push-button matrix and reports press events over USB serial (9600 baud).

## Button matrix

16 plain push buttons wired as a 4x4 matrix — no external resistors or
diodes needed: rows are driven outputs and columns use the internal
pull-ups (`INPUT_PULLUP`).

| Pins | Function |
|---|---|
| 2-5 | Rows (outputs, one driven LOW at a time) |
| 6-9 | Columns (`INPUT_PULLUP`, LOW = pressed) |

Without diodes, three buttons pressed at once forming a rectangle can
produce a ghost key; single presses are unaffected.

## Serial events

Output over USB at 9600 baud, format `<EVENT> <row> <col>` with 1-based
row/column numbering:

| Event | Meaning |
|---|---|
| `DOWN 2 3` | button pressed |
| `UP 2 3` | button released |
| `PRESS 2 3` | short press: released after less than `LONG_PRESS_MS` (1000 ms) |
| `LONG_PRESS 2 3` | long press: released after `LONG_PRESS_MS` (1000 ms) or more |
| `PRESSED 2 3` | repeat, emitted every `REPEAT_MS` (500 ms) while held |

Example (short press of row 1, column 2):

```
DOWN 1 2
PRESSED 1 2
UP 1 2
PRESS 1 2
```

Debounce is `DEBOUNCE_MS` (20 ms); all constants live at the top of
`src/main.cpp`.

## USB identification

This board is an Arduino Micro identical to the PowerAndPots one (same VID:PID,
no unique USB serial). `platformio.ini` sets
`board_build.usb_product = Jukebox Keyboard`, so it enumerates with the product
string **"Jukebox Keyboard"** (`/dev/serial/by-id/usb-Jukebox_Keyboard_*-if00`),
which lets the host address it independently of the USB port.

## Build and flash

[PlatformIO](https://platformio.org/) project:

```sh
pio run                # build
pio run -t upload      # flash
pio device monitor     # serial monitor (9600)
```

On Linux, install the udev rules so the Micro's port is accessible
without root:

```sh
sudo cp 99-platformio-udev.rules /etc/udev/rules.d/
sudo udevadm control --reload-rules && sudo udevadm trigger
```

`99-platformio-udev.rules` is PlatformIO's standard file (Apache 2.0).

## Layout

```
src/main.cpp                  # matrix scan, debounce and event reporting
99-platformio-udev.rules      # PlatformIO udev rules (Linux)
```

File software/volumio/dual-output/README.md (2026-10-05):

# jukebox dual output (Volumio + Raspberry Pi)

Adds a second, **constant-level** audio output while keeping the I2S DAC as
the main, volume-controlled output, plus a **bass/treble tone control** on the
speaker path.

What you get:

| Output | Level | Tone control |
| --- | --- | --- |
| I2S DAC (speakers) | controlled by the normal Volumio volume slider / API / MPD | **bass + treble** (CamillaDSP) |
| Second output (spectrum analyser) | constant level; not affected by volume | none (stays untouched) |

Both outputs always play the same stream, simultaneously.

## Tone control (bass / treble)

The DAC branch carries a low-shelf and a high-shelf biquad, applied by
[CamillaDSP](https://github.com/HEnquist/camilladsp) through the ALSA `cdsp`
plugin (shipped precompiled in this directory, source + `strrep.h` in `cdsp/`).

```
volumio -> softvolume -> jukeboxRoute -> jukeboxSplit (multi)
    |- volumioSoftVol (SoftMaster: volume/balance)
    |      '- jukeboxTone (cdsp -> CamillaDSP: Lowshelf + Highshelf) -> DAC
    '- jukeboxEq (analyser bass trim) -> USB/HDMI/jack  (analyser)
```

* Both shelves default to **0.0 dB**, which is bit-for-bit transparent.
* `jukebox-pots` rewrites the two gains in the CamillaDSP config and sends it
  a `SIGHUP`, so the tone changes **live**, without stopping playback.
* The tone applies to the **DAC branch only**; the analyser feed is not
  affected by the tone (by design).
* CamillaDSP runs at the file's native rate (the `cdsp` plugin substitutes
  `$samplerate$`/`$format$`/`$channels$` on every open), so hi-res files are
  not resampled.
* `chunksize` is **512** on purpose: a larger chunk than the plugin's pipe
  buffer deadlocks the stream (the player waits forever in `poll()`); 512
  matches it.
* Tone options: `--no-tone` (`JB_TONE=off`), `--tone-bass HZ`,
  `--tone-treble HZ`, `--tone-q Q`. Rebuild the plugin on the host with
  `JB_TONE_BUILD_CDSP=1` (needs `gcc` + `libasound2-dev`).

## Choosing the second output

| `--second-output` | Device | Notes |
| --- | --- | --- |
| `usb` | a **USB sound card / DAC** (any extra ALSA card) | **Recommended.** Independent device, no interference with display or jack. |
| `hdmi` | an **HDMI audio extractor** | Digital end-to-end (no PWM noise), but on this Pi it can grab the DSI touch screen as a DRM output and disable the touch_display plugin. Test before adopting. |
| `jack` | the Pi **3.5 mm jack** | Simple, but the jack is a PWM output prone to conducted noise (fixed pattern visible in an analyser). |
| `none` | — | Only the DAC plays (no second output). |

The installer auto-detects the cards; if the chosen second output is not
present at install time (e.g. USB unplugged), it installs a **DAC-only
fallback** and switches to the full dual chain automatically when the device
appears (udev handles hotplug).

## Install

From this directory (the deploy wrapper copies the package — scripts, the
engine and its binaries under `files/` — to the Pi and runs it there):

```sh
./deploy.sh install --second-output usb     # or: hdmi / jack / none
```

Or directly on the Volumio host (run the engine inside `files/`):

```sh
sudo ./files/jukebox-audio.sh install --second-output usb
```

The installer:

1. backs up the current ALSA / Volumio / MPD configuration to
   `/var/backups/jukebox-audio/<timestamp>/`,
2. replaces Volumio's `softvolume.postVolume.conf` ALSA contribution with a
   split chain (DAC branch with software volume + tone, second branch fixed
   level),
3. writes the matching `/etc/asound.conf`,
4. installs CamillaDSP and the `cdsp` ALSA plugin and writes the tone-control
   config for every variant (skipped with `--no-tone`),
5. points Volumio's volume settings at the DAC's `SoftMaster`,
6. disables MPD's own mixer and adds buffer settings so MPD opens the split
   chain reliably,
7. installs systemd units (boot guard + path watcher) and a udev rule that
   re-assert the configuration if Volumio rewrites it or the second device
   is plugged/unplugged,
8. keeps only the DAC branch active whenever the second device is missing.

A reboot is recommended after installing.

## Verify / operate

```sh
./deploy.sh verify --with-playback   # checks all the moving parts
./deploy.sh status
./deploy.sh uninstall                # restores the backups
```

`verify` checks the ALSA chain, the volume-control binding, MPD settings,
the second output state (USB card / HDMI EDID / jack level) and opens the
chain on both outputs. With `--with-playback` it also plays the MPD queue
briefly (at low volume) to check the real playback path; if the queue is empty
(e.g. right after a reboot) it pulls a track from the library so there is
something to play, then cleans it up — the test only fails if the audio path is
really broken, not because the queue happened to be empty.

## How it works

```
volumio -> softvolume -> jukeboxRoute -> jukeboxSplit (multi)
    |- volumioSoftVol (softvol, SoftMaster) -> jukeboxTone -> postVolume -> volumioOutput -> volumioHw (I2S DAC)
    '- jukeboxEq (analyser bass trim) -> jukeboxUsb | jukeboxHdmi | jukeboxJack             (fixed level)
```

* The software volume (`SoftMaster`) sits **after** the split, on the DAC
  branch only, so both the Volumio UI/API and MPD move the DAC alone.
* `jukeboxTone` (the `cdsp` -> CamillaDSP tone step) sits **after** the
  software volume, so the bass/treble shelves act on the DAC signal only.
  Without the tone (`--no-tone`) it is absent and the chain is the original one.
* The second branch has no volume control at all: its level is inherently
  constant (USB/HDMI) or pinned by keeping the jack mixer at full level.
* Volumio's ALSA config generator produces `/etc/asound.conf` from plugin
  contributions. The contribution file is replaced in place, so a normal
  regeneration yields the same split chain instead of flattening it.

### Tone control (CamillaDSP + cdsp)

The DAC branch runs a low-shelf + high-shelf biquad in CamillaDSP, inserted
with the ALSA `cdsp` plugin:

* **Live changes**: `jukebox-pots` edits the two `gain:` values in the
  CamillaDSP config and sends the running process a `SIGHUP`; CamillaDSP
  reloads the config without interrupting playback (filters are rebuilt
  in place).
* **Native rate**: the plugin substitutes `$samplerate$`, `$format$` and
  `$channels$` on every open, so CamillaDSP always runs at the file's rate
  (44.1k/48k/96k/192k...). Nothing is resampled.
* **Transparent by default**: both shelves default to `0.0 dB`.
* **`chunksize: 512` is deliberate.** The `cdsp` plugin hands audio to
  CamillaDSP through a pipe; if CamillaDSP's chunk is larger than a full pipe
  the reader waits for more data than the writer will send and the player
  blocks forever in `poll()` (XRUN). 512 matches the plugin's buffer.
* The plugin source is in `cdsp/` (`libasound_module_pcm_cdsp.c` +
  `strrep.h`). It is shipped precompiled for armhf; rebuild it on the host
  with `JB_TONE_BUILD_CDSP=1 ./jukebox-audio.sh install` (needs `gcc` and
  `libasound2-dev`), or cross-compile with
  `arm-linux-gnueabihf-gcc -DPIC -std=gnu11 -O2 -fPIC -shared` (a
  `debian:bookworm` container with `gcc-arm-linux-gnueabihf` plus
  `libasound2-dev:armhf` via multiarch works too).
  Four fixes over upstream are included: exec argument lifetime (the `-f/-r/-n`
  flags used to arrive empty), CamillaDSP v4 sample-format names, an atomic
  active-config write (temp file + `rename`, forced mode `0666`) so the file
  stays writable whichever user opened the chain last (root at install time,
  `mpd` during playback), and underrun concealment: when the application stops
  feeding for more than a period the plugin feeds CamillaDSP silence instead
  of reporting a fatal XRUN, so a temporary player stall (slow storage, system
  load) cannot kill the output.
* `CamillaDSP` (v4.1.3, `camilladsp-linux-armv7.tar.gz`) is shipped as
  `camilladsp` and installed to `/usr/local/bin/`.

### Analyser bass trim

Spectrum analysers commonly over-read the deep bass because of their hardware,
so the **analyser branch only** can be trimmed with a fixed low-shelf filter.
It is off the speaker path entirely.

* Implemented with the CAPS `Eq4p` LADSPA plugin through the `alsaequal`
  `equal` ALSA plugin (`caps` + `libasound2-plugin-equal`, installed
  automatically).
* Bands `b`/`c`/`d` are disabled; band `a` is a low shelf at the corner
  frequency. `50 %` amplitude is **-6.02 dB**.
* Defaults: **60 Hz, -6.02 dB, Q 0.5**. Measured response on the live chain:

  | Hz | 20 | 30 | 40 | 50 | 60 | 80 | 100+ |
  |----|----|----|----|----|----|----|------|
  | dB | -6.3 | -6.4 | -6.1 | -4.8 | -3.0 | -0.5 | ~0 |

* The parameters are baked into a **deterministic controls file**
  (`/usr/local/jukebox-audio/analyser-eq.bin`, copied to
  `/var/lib/jukebox-audio/analyser-eq.bin`), so the filter is byte-identical
  on every install.
* Options: `--analyser-trim on|off` (`--no-analyser-trim`), `--analyser-freq HZ`,
  `--analyser-gain dB`, `--analyser-q Q`; or the matching `JB_ANALYSER_*`
  environment variables.
* The wrapper `plug` must pin `rate` + `FLOAT_LE` around `equal` (it only
  accepts float); without that the ALSA `multi` plugin fails to negotiate and
  the whole chain refuses to open.

### Fail-safe

The ALSA `multi` plugin is all-or-nothing: if one branch cannot open, the
whole chain fails (no sound at all, speakers included). Since the second
device can disappear (USB unplugged, extractor off, ...), the chain is
managed dynamically:

* second device absent -> **daconly** variant: only the DAC plays;
* second device present -> full dual-output variant.

The decision runs at boot, on device hotplug (udev) and whenever the watched
files change. All variants are kept in `/usr/local/jukebox-audio/` and the
live one is selected automatically. `JB_USB_OVERRIDE=on|off` (or
`JB_HDMI_OVERRIDE`) force the verdict for testing.

## Notes and caveats

* Cards are auto-detected (`sndrpirpidac` as DAC, the extra USB card as the
  second output). Override with `JB_DAC_CARD=`, `JB_JACK_CARD=`,
  `JB_HDMI_CARD=`, `JB_USB_CARD=`.
* USB/HDMI sample rate is `48000` by default (`JB_USB_RATE` / `JB_HDMI_RATE`).
* Jack reference level is `0 dB` (`JB_JACK_LEVEL` / `JB_JACK_LEVEL_RAW`).
* Analyser bass trim defaults to `on` at `60 Hz / -6.02 dB / Q 0.5`
  (`JB_ANALYSER_TRIM`, `JB_ANALYSER_FREQ_HZ`, `JB_ANALYSER_GAIN_DB`,
  `JB_ANALYSER_Q`). Set `--no-analyser-trim` for a transparent second branch.
* Tone control defaults to `on` at `120 Hz` (bass) / `6000 Hz` (treble),
  `Q 0.7` (`JB_TONE`, `JB_TONE_BASS_FREQ`, `JB_TONE_TREBLE_FREQ`,
  `JB_TONE_Q`). `--no-tone` removes the CamillaDSP step entirely. The gains
  themselves are owned by `jukebox-pots` (see that package).
* The `multi` chain needs `buffer_time`/`period_time` in MPD (installed via
  Volumio's `special_cards_config.json`); without them MPD may refuse to
  open the chain. The buffer is deliberately large (`3000000` us = 3 s,
  period `50000` us): it absorbs player stalls (slow SD card, load spikes)
  so the DAC branch never starves. Even longer stalls are concealed by the
  plugin's silence feed (see above).
* `/var/lib/jukebox-audio` is kept world-writable (`0777`): MPD's `cdsp`
  plugin (unprivileged) rewrites CamillaDSP's active config there on every
  open, and `jukebox-pots` edits it too. The active config itself is written
  atomically (temp file + `rename`) and forced to `0666`, so a root-created
  copy (install/verify opens the chain as root) can never block `mpd`; the
  installer/guard also re-asserts `0666` with `fix_active_perms`. The tone
  templates under `/usr/local/jukebox-audio/cdsp/` are `0644`.
* **Analysers:** the tone acts on the DAC branch only. The spectrum analyser
  feed keeps the fixed-level signal (and its own bass trim).
* **HDMI caveat:** on this Pi, activating an HDMI output can take over the
  DRM/KMS display configuration and stop the DSI touch screen
  (`touch_display` plugin). Use `--second-output usb` if you need the touch
  screen.
* Uninstall restores the most recent backup
  (`/var/backups/jukebox-audio/latest`).
* **Re-running `install` does not poison the backup.** The restore point is
  captured only from a *clean* (not yet jukebox-managed) configuration: once the
  live ALSA files carry the jukebox markers, a re-install keeps the existing
  backup instead of overwriting it with an already-managed state. If a backup
  file is itself a managed state (from an old installer version) `uninstall`
  does not restore it; it removes the managed file and lets Volumio regenerate
  its own configuration.

## Layout

```
deploy.sh                   # scripts (repo root): ship the package + run it over SSH
uninstall.sh                # thin wrapper around the engine's uninstall mode
README.md                   # this file
files/                      # everything that lands on the host
  jukebox-audio.sh          # installer / verify / status / apply / uninstall (engine)
  jukebox-audio-guard.service / .path  # systemd guard units
  89-jukebox-audio.rules    # udev rule (HDMI/USB hotplug)
  camilladsp                # CamillaDSP v4.1.3, armv7 build (precompiled)
  libasound_module_pcm_cdsp.so  # cdsp ALSA plugin, armhf (precompiled)
  cdsp/
    libasound_module_pcm_cdsp.c  # plugin source (patched: see "Tone control")
    strrep.h                # substring-replace helper used by the plugin
```

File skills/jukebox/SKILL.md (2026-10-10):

---
name: jukebox
description: Operate and troubleshoot the user's homemade jukebox — a Raspberry Pi 4B running Volumio with a custom dual audio output (I2S DAC speakers, volume-controlled; a second fixed-level output, currently a USB sound card, feeding a hardware spectrum analyser) and a DSI touch screen. Use this skill whenever the user mentions "the jukebox", "la jukebox", "el jukebox", "Volumio", "la rocola", the music box, its audio/volume/spectrum analyser/touch screen, its music storage/HDDs (RAID), or asks to connect to it, SSH in, check/fix/change its sound or storage setup, or run the audio installer — even when they don't explicitly say "jukebox".
---

# Jukebox (Volumio on Raspberry Pi)

## What this is

A homemade jukebox: Raspberry Pi 4B running **Volumio** (Raspbian bookworm,
kernel 6.12.y) with:

- **I2S DAC** (PCM1794A, ALSA card `sndrpirpidac`) → speakers. Volume-controlled.
- **Second fixed-level output** for a hardware spectrum analyser. Currently a
  **USB sound card** (`USB PnP Sound Device`, PCM2902). Its ALSA card number is
  dynamic — always find it by name.
- **DSI touch screen** (plugin `touch_display`, `volumio-kiosk.service`,
  Xorg on :0).
- The 3.5 mm jack and both HDMI outputs exist but are **not** in use.
- **Two 3.5" HDDs in USB enclosures, RAID 1** (mirrored) holding the music
  library, mounted at `/media` — which is what Volumio's `USB` source symlinks
  to. Set up / adopted with `software/storage/raid-music.sh`. See below.

The audio chain is custom ("jukebox-audio"): an ALSA `multi` split where the
software volume (`SoftMaster`) sits only on the DAC branch, so the Volumio
volume slider moves the speakers and never the analyser feed. MPD's own mixer
is disabled (`mixer_type "none"`) — `mpc volume` answering "No mixer" is
**expected**, not a bug. Control volume through Volumio (UI or API).

## Connecting

```sh
ssh volumio@<host>          # Volumio box: login user is `volumio`
```

`<host>` is whatever mDNS name or IP the user set up (Volumio's default
hostname is `volumio`). If the name doesn't resolve, ask the user or discover it:

```sh
avahi-browse -rt _ssh._tcp        # find SSH-advertising hosts on the LAN
```

No passwords are stored anywhere (deliberately). `sudo` on the box needs the
user's password — ask for it, or have them run
`JUKEBOX_PASSWORD=... ./deploy.sh ...` from their machine. Never hardcode
credentials into files.

## Install / operate everything

From the repo (development machine) a single wrapper drives every package over
SSH in dependency order — `dual-output` → `ui-boost` → `jukebox-pots` →
`pot-overlay` → `ui-nav` → `jukebox-keyboard` (reversed for uninstall):

```sh
./deploy-all.sh -H user@host install      # every package; second output fixed to usb
./deploy-all.sh -H user@host verify
./deploy-all.sh -H user@host status
./deploy-all.sh -H user@host uninstall
# password for sudo (host is required: -H or $JUKEBOX_HOST)
./deploy-all.sh -H volumio@<host> -p <pass> install
```

The host is **required**: pass `-H user@host` (or set `JUKEBOX_HOST`); there is
no built-in default. Use `-p <password>` (or `JUKEBOX_PASSWORD`) when `sudo` on
the box needs one. It just sequences each package's own `deploy.sh`, so
package-specific one-off options (`--second-output`, `--key-action`, …) still
go through the per-package `deploy.sh`. For this box `install` fixes the second
output to `usb`. The pot power button (short press halts the Pi; relay cut after
the Arduino-side delay) is on by default. Per package, for example:

```sh
software/jukebox-pots/deploy.sh -H volumio@<host> -p <pass> install
software/jukebox-pots/deploy.sh -H volumio@<host> install --no-power-button
software/jukebox-pots/deploy.sh -H volumio@<host> install --power-off-delay 45
software/jukebox-keyboard/deploy.sh -H volumio@<host> install --key-action next 1,4
```

## Expected state after login (checklist)

| Check | Command | Expected |
|---|---|---|
| Services | `systemctl is-active volumio mpd volumio-kiosk` | all `active` |
| Volumio API | `curl -s localhost:3000/api/v1/getState` | JSON with `status`, `volume` |
| Live variant | `grep variant /etc/asound.conf` | `# jukebox-audio variant: usb` |
| Volume control | `amixer -c sndrpirpidac sget SoftMaster` | readable 0–99 control |
| Guard units | `systemctl is-enabled jukebox-audio-guard.service jukebox-audio-guard.path` | both `enabled` |
| Pot service | `systemctl is-active jukebox-pots` | `active` (if installed) |
| Keyboard service | `systemctl is-active jukebox-keyboard` | `active` (if installed) |
| Pot port | `ls /dev/ttyACM*` | the PowerAndPots/Keyboard Arduino (if plugged) |
| Tone engine | `systemctl is-active jukebox-pots` + `pgrep -x camilladsp` | service active; CamillaDSP runs only while playing |
| Tone config | `ls /usr/local/jukebox-audio/cdsp/camilla.*.yml` | one template per variant (`0644`) |
| Tool | `sudo /usr/local/jukebox-audio/jukebox-audio.sh status` | `second output: usb`, `live variant: usb` |
| UI boost | `sudo /usr/local/jukebox-ui/jukebox-ui.sh verify` | all `ok`, X screen `800x480` |
| UI guard | `systemctl is-active jukebox-ui-guard.path` | `active` |
| Pot overlay | `systemctl is-active jukebox-overlay.service` | `active` (port 3210) |
| UI nav | `systemctl is-active jukebox-ui-nav.service` | `active` (port 3211) |
| Keyboard | `systemctl is-active jukebox-keyboard.service` | `active` (if installed) |
| RAID array | `cat /proc/mdstat` | `md0 ... [2/2] [UU]` |
| Music disk mount | `findmnt /media` | `ext4`, source `/dev/md0` |
| USB storage quirk | `grep -o 'usb-storage[^ ]*' /boot/cmdline.txt` | `usb-storage.quirks=152d:0583:u` |

If the USB card is unplugged, the chain automatically falls back to DAC-only
(speakers keep playing); plug it back and the guard/udev re-activates the split
within seconds. That is by design.

## The jukebox-audio tool

Canonical files + helper live in `/usr/local/jukebox-audio/`; the engine is in
this repo at `software/volumio/dual-output/files/jukebox-audio.sh` (full design
docs in its README).

```sh
sudo /usr/local/jukebox-audio/jukebox-audio.sh status     # quick overview
sudo /usr/local/jukebox-audio/jukebox-audio.sh verify     # full checks (--with-playback also tests MPD playback)
sudo /usr/local/jukebox-audio/jukebox-audio.sh apply      # re-assert current config (idempotent)
sudo /usr/local/jukebox-audio/jukebox-audio.sh install --second-output usb|hdmi|jack|none
sudo /usr/local/jukebox-audio/jukebox-audio.sh uninstall  # restore the pre-install backup
```

**Analyser bass trim.** The analyser (second) branch carries a fixed low-shelf
filter so the spectrum analyser's hardware bass over-read is compensated. It is
on the second branch only; the speakers are untouched. Defaults: `60 Hz,
-6.02 dB (= half amplitude), Q 0.5`, which gives ~-6 dB below 40 Hz and flat
above ~80 Hz. Implemented with CAPS `Eq4p` via the `alsaequal` `equal` plugin
(auto-installed). Change with `--analyser-trim on|off`, `--analyser-freq HZ`,
`--analyser-gain dB`, `--analyser-q Q` (or `JB_ANALYSER_*`); the value is baked
into a deterministic `/var/lib/jukebox-audio/analyser-eq.bin`. `status` shows
it as `analyser trim :`.

- Log: `/var/log/jukebox-audio.log`; backups: `/var/backups/jukebox-audio/latest/`.
- `jukebox-audio-guard.path` watches `/etc/asound.conf`, the Volumio ALSA
  snippet and `special_cards_config.json`: if Volumio rewrites them from its
  UI, the guard restores the correct config and restarts MPD. If you hand-edit
  those files the guard will revert them — edit the canonical copies in
  `/usr/local/jukebox-audio/` and run `apply` instead (or stop the path unit
  while experimenting).
- From a dev machine: `software/volumio/dual-output/deploy.sh install
  --second-output usb` copies the installer over SSH and runs it remotely.

## The jukebox-ui tool (touch screen speed)

The touch UI was sluggish/scrolling badly because Chromium was forced into
software compositing, the `now_playing` UI used very heavy CSS blurs, and a
phantom HDMI output forced the X screen to 848px over an 800px panel. Fixed by
`software/volumio/ui-boost/` (canonical copies in `/usr/local/jukebox-ui/`).
Install/deploy with `software/volumio/ui-boost/deploy.sh install` (or its
`install.sh` on the host); a reboot makes it take effect.

```sh
sudo /usr/local/jukebox-ui/jukebox-ui.sh status   # overview + X screen
sudo /usr/local/jukebox-ui/jukebox-ui.sh verify    # pass/fail checks
sudo /usr/local/jukebox-ui/jukebox-ui.sh apply     # re-assert (used by guard)
```

- Log: `/var/log/jukebox-ui.log`.
- `jukebox-ui-guard.path` watches `/opt/volumiokiosk.sh` and
  `/etc/chromium.d/00-rpi-vars`; saving a setting on the Touch Display page
  regenerates the kiosk script, and the guard re-applies the fixes. Same
  trap as the audio guard: edit canonical copies + `apply`, don't hand-edit.
- After updating the `now_playing` plugin, its CSS is replaced: run
  `apply` manually once.
- The HDMI-off hook turns the phantom output off inside the X session; do
  **not** enable HDMI audio (see golden rules).

## Disks / RAID (music library)

The music library lives on **two 3.5" HDDs in USB enclosures, mirrored (RAID
1)** and mounted at `/media` (Volumio's `USB` source). The on-host helper is in
this repo at `software/storage/raid-music.sh` (design doc in its README). It is
**not a package** — run it by hand:

```sh
scp software/storage/raid-music.sh volumio@<host>:/tmp/
ssh volumio@<host> 'echo <pass> | sudo -S -p "" bash /tmp/raid-music.sh install'
sudo bash /tmp/raid-music.sh status     # array, mount, disks, SMART
sudo bash /tmp/raid-music.sh verify     # pass/fail
sudo bash /tmp/raid-music.sh apply      # re-assert config + mount
```

- **Idempotent & safe**: an existing array is only *adopted* (never reformatted);
  with no array it uses two *empty* disks and **refuses** a disk that has data
  unless `--reformat` is passed.
- Array `/dev/md0`, ext4 label `MUSIC`; music goes in `/media/Music/` (the SMB
  **`USB`** share).
- Boot assembly comes from `/etc/mdadm/mdadm.conf` + `/etc/fstab`; `raid1` /
  `md_mod` are pinned in `/etc/modules-load.d/raid.conf`.
- `install` also pins the JMS583 workaround `usb-storage.quirks=152d:0583:u` in
  `/boot/cmdline.txt` (see golden rules). A Volumio update can drop it.

## Common tasks

**Change/read volume (the supported way):**
```sh
curl -s 'localhost:3000/api/v1/commands/?cmd=volume&volume=42'
curl -s localhost:3000/api/v1/getState | grep -o '"volume":"[0-9]*"'
```

**Play / pause / status:** `mpc play`, `mpc stop`, `mpc status` (MPD is
Volumio's playback engine).

**Add music over SMB:** the box runs Samba with guest shares and advertises
itself as host **`Jukebox`**, so it shows up by itself in the file manager's
Network view. Shares: `USB` (`/mnt/USB` → the RAID music library), `Internal
Storage` (`/data/INTERNAL`, the SD card — small) and `NAS` (`/mnt/NAS`) — no
password, connect as guest. Put music in the **`USB`** share's `Music/` folder
(or at its root). Mount from Linux with
`sudo mount -t cifs '//<host>/USB' /mnt/jukebox -o guest`.
After copying, rescan with `mpc update` (Volumio's REST API has **no**
`updateLibrary`/`rescan` command; the UI button uses MPD's socket).

**Check that both outputs are really playing:**
```sh
mpc play; sleep 5
for c in $(awk '/^ *[0-9]+ \[/ {print $1}' /proc/asound/cards); do
  echo "card$c: $(head -1 /proc/asound/card$c/pcm0p/sub0/status 2>/dev/null)"
done
# expect: sndrpirpidac RUNNING AND the USB card RUNNING
```

**Quick silent chain test (opens both branches, no UI interaction):**
`aplay -D volumio -f S16_LE -r 44100 -c 2 -d 3 /dev/zero` then check the two
states above.

**Find cards by name (numbers can shift across boots!):**
`cat /proc/asound/cards`; path symlinks exist per name, e.g.
`/proc/asound/sndrpirpidac`.

## Golden rules / traps

- **Never use an HDMI output for audio.** On this Pi it grabs the DRM display
  and kills the DSI touch screen (`touch_display` plugin). This already
  happened once; the USB second output exists because of it. The `hdmi`
  variant is still supported for other setups, but don't enable it here unless
  the user explicitly asks and accepts the touch-screen risk.
- **The analyser feed must stay at constant level.** All volume control
  belongs to `SoftMaster` on `sndrpirpidac`. If volume "stops working" on the
  DAC or starts affecting the second output, run `verify` and confirm
  `softvolume=true`, `mixer=SoftMaster`, `mixer_type=Software` in
  `/data/configuration/audio_interface/alsa_controller/config.json`.
- **Card numbers change** when devices are added/removed (boot order, USB
  hotplug). Everything is wired by *name* (`hw:CARD=...`, `/proc/asound/<name>`).
  Don't "fix" anything by writing numeric card indices into configs.
- **`mpc volume` doesn't work on purpose** (MPD mixer disabled). Don't
  "repair" that by re-enabling MPD's mixer — it would let MPD touch the jack /
  second output control.
- **Re-installing is safe**: `install` is idempotent and takes a fresh backup.
  It's the go-to fix if the audio config gets mangled. The `multi` split is
  all-or-nothing: if one branch can't open, everything is silent — the
  fail-safe avoids that by keeping only the DAC branch while the second device
  is away.
- **The active CamillaDSP config must stay writable by `mpd`.** The `cdsp`
  plugin rewrites `/var/lib/jukebox-audio/camilla-active.*.yml` on every open;
  it runs as `mpd` for playback but as root during install/verify. Never
  pre-create that file as `root:0644` (or `chmod 0644` it): playback then
  dies after ~1 s with `Error writing output config file` in `mpd.log`. The
  plugin now writes it atomically and forces `0666`, and `apply`/`install`
  re-assert the mode (`fix_active_perms`).
- **Underruns must never be fatal.** MPD runs a 3 s ALSA buffer on the split
  chain (`buffer_time "3000000"` in `special_cards_config.json`) and the
  `cdsp` plugin feeds silence when the application stalls, instead of raising
  an XRUN. Don't shrink that buffer or reintroduce the fatal path: a player
  hiccup would surface as "failed to open output device" in Volumio.
- **The two music HDDs need their own power, and they must not use UAS.** They
  are 3.5" drives in cheap USB enclosures; the USB bus cannot power them, and a
  mirror writes to both at once, so underpowered drives drop off the bus under
  load (USB disconnects, I/O errors, a degraded array). These JMicron JMS583
  bridges are also unstable with the **UAS** driver, so `/boot/cmdline.txt`
  pins `usb-storage.quirks=152d:0583:u` (Bulk-Only Transport). A Volumio update
  can reset `cmdline.txt` and the cuelgues return — re-run
  `software/storage/raid-music.sh install`.
- Reboots are normal after audio changes; the guard + `alsa-restore` restore
  everything (including the `SoftMaster` element) on boot.

## Troubleshooting quick table

| Symptom | Likely cause | Fix |
|---|---|---|
| No sound at all | chain broken, or second device vanished mid-session | `status`; if variant `daconly`, replug USB; then `apply` |
| Speakers fine, no analyser feed | USB card absent or variant `daconly` | replug, wait ~10 s (udev), else `install --second-output usb` |
| Volumio volume slider does nothing | `SoftMaster` element lost | `systemctl restart alsa-restore`; `apply` |
| Volume affects the analyser too | wrong variant / mixer binding | `verify`, then `install --second-output usb` |
| Touch screen dead | something enabled HDMI audio/DRM output | check `/boot/userconfig.txt` and the touch_display plugin config; reboot; re-run `install --second-output usb` if the HDMI variant sneaked in |
| Arduino never shows as `ttyACM*`, `lsusb` clean, but LEDs on | 32U4 needs VBUS sense; a clone (Pro Micro) powers up without it | bridge the Pro Micro `J1`/`SJ1` jumper (VCC->UVCC/VBUS), or wire `5V`/`VCC` to the VBUS net. See `software/jukebox-pots/README.md` |
| Restarting `jukebox-pots` cuts the jukebox power | **DTR reset**: DTR is tied to reset on the Micro (same board runs the power state machine) | the daemon must not assert DTR (it does not); do not use `cat`/tools that raise DTR |
| Pots do nothing but `jukebox-pots` is active | board not enumerated, wrong port, or `SoftMaster` missing | `sudo /usr/local/jukebox-pots/jukebox-pots.py --probe`; `journalctl -u jukebox-pots` |
| Tone pots do nothing | tone off (`JB_TONE`), no CamillaDSP config, or the daemon can't write it | check `ls /usr/local/jukebox-audio/cdsp/`; `journalctl -u jukebox-pots \| grep tone`; reinstall `jukebox-audio` with tone on |
| No sound after installing the tone | CamillaDSP `chunksize` too large for the cdsp pipe (deadlock, XRUN) | keep `chunksize: 512` in the tone template; `apply`; reinstall |
| Power button short press does nothing | `JP_POWER_BUTTON=0` (disabled), or firmware not reflashed | install `jukebox-pots` without `--no-power-button`; reflash the PowerAndPots Arduino; check `journalctl -u jukebox-pots` |
| Pi shuts down but the relay never cuts | firmware without the `POWER: off` command, or serial port dead at shutdown | reflash the Arduino; the cut is Arduino-side (`POWER_OFF_DELAY_MS`, default 30 s) |
| Pi halts on a short press but you wanted a hard cut | long press (≥ 5 s) is the immediate cut; it also cancels a pending soft-off | hold the button ≥ 5 s |
| Music plays a while, then Volumio says "failed to open output device" | player underrun escalated to a fatal XRUN (old plugin, or buffer too small) | update the plugin + `apply` (3 s buffer, silence concealment); check `mpd.log` for `XRUN`/`Broken pipe` |
| Plays ~1 s (analyser blips) then stops; `mpd.log` shows `Error writing output config file` | active CamillaDSP config not writable by `mpd` (stale `root:0644` copy) | `chmod 0666 /var/lib/jukebox-audio/camilla-active.*.yml`, then `apply`; the plugin now writes it atomically with mode 0666 |
| Tone stops after reboot | CamillaDSP config regenerated without gains | the installer preserves gains; re-check `grep gain /usr/local/jukebox-audio/cdsp/camilla.*.yml` |
| Chain refuses to open | files hand-edited and guard reverted mid-play, or device busy | `mpc stop`; `apply`; `verify --with-playback` |
| Overlay never shows | server down, nothing connected, or UI loader gone | `systemctl status jukebox-overlay`; `curl localhost:3210/state`; `sudo /usr/local/jukebox-overlay/apply.sh`; restart `volumio-kiosk` |
| Overlay gone after a Volumio update | `index.html` rewritten | `systemctl start jukebox-overlay-guard.service` (re-injects), or re-run `apply.sh` |
| A keyboard key does nothing | key not mapped, or wrong board | `journalctl -u jukebox-keyboard` (shows `unmapped key r,c`); identify with `jukebox-keyboard.py --watch`, edit `software/jukebox-keyboard/files/keymap.conf` and re-install (or a one-off `--key-action <action> r,c`) |
| Music array degraded (`[2/1]`) or a disk missing | a disk dropped — almost always power/USB, not the disk | `cat /proc/mdstat`; `dmesg \| grep -iE 'usb\|uas\|reset\|I/O error'`; fix the PSU; then `sudo mdadm /dev/md0 --add /dev/sdX` and wait for `[2/2] [UU]` |
| `USB` share / `/media` empty or not mounted | array not assembled, or the fstab entry is gone | `sudo software/storage/raid-music.sh apply` (or `install`); `cat /proc/mdstat` |
| Disks keep disconnecting under load | underpowered USB supply, or UAS still active | use a powered PSU/hub; re-run `raid-music.sh install` to re-pin `usb-storage.quirks=152d:0583:u`, then reboot |

## Repo map (for reference)

- `software/volumio/dual-output/` — scripts (`deploy.sh`, `uninstall.sh`) plus
  `files/` with the engine (`jukebox-audio.sh`), the guard units/udev rule, the
  armv7 `camilladsp` binary and the armhf `cdsp` plugin + source. Full design doc
  in its README (the ALSA split, the CamillaDSP tone step, variants, the `multi`
  fail-safe).
- `software/jukebox-pots/` — `jukebox-pots.service`: reads `POT volume` /
  `POT balance` / `POT single` / `POT multi second` from the PowerAndPots
  Arduino over USB serial and drives the DAC volume (Volumio API), balance
  (per-channel `SoftMaster`) and bass/treble (CamillaDSP config + `SIGHUP`, live).
  Install with `software/jukebox-pots/deploy.sh install`; check with `... status`.
  It only touches the DAC branch, never the analyser feed. It also watches the
  Arduino's `POWER:` lines: a short power-button press halts the Pi and the
  Arduino cuts the relay ~30 s later (delay lives on the board, powered from
  5VSB); the long press stays the immediate hard cut. On by default; disable
  with `--no-power-button`.
- `software/volumio/pot-overlay/` — on-screen circular indicator for balance /
  bass / treble (Volumio's own volume indicator covers volume only). The daemon
  POSTs each change to a tiny stdlib HTTP/SSE server (`/usr/local/jukebox-overlay`,
  port 3210) and the UI loads `overlay.js` (injected into `/volumio/http/www*/index.html`
  by `apply.sh`, kept in place by `jukebox-overlay-guard.path`). The client reuses
  the UI's bundled jQuery-knob so it looks like the volume indicator. Install with
  `software/volumio/pot-overlay/deploy.sh install` (after jukebox-pots).
- `software/volumio/ui-nav/` — daemon → UI navigation channel (port 3211): a small
  stdlib HTTP/SSE server plus an injected `ui-nav.js` that drives the UI's
  ui-router `$state`. A daemon POSTs `{"type":"nav","view":"toggle"|"home"|"queue"}`
  to switch between the now-playing home and the play queue. Used by the
  keyboard's open/close key; separate from `pot-overlay` on purpose.
  Install with `software/volumio/ui-nav/deploy.sh install`.
- `software/jukebox-keyboard/` — `jukebox-keyboard.service`: reads the
  KeyboardArduino's key events (`DOWN`/`UP`/`PRESS`/`LONG_PRESS`/`PRESSED`) and on
  key **press** runs the mapped Volumio command (play/pause/stop/prev/next/mute/
  clear, favourite toggle, save queue as playlist, or open/close the queue view).
  The key map is **versioned in the repo** at
  `software/jukebox-keyboard/files/keymap.conf` (`ACTION=ROW,COL`) and installed
  as-is, so a fresh/re-installed box gets the same keys; a one-off
  `--key-action ACTION ROW,COL` overrides single entries. The installed copy is
  `/usr/local/jukebox-keyboard/config.env` (`JK_KEY_<action>=row,col`);
  identify a key with `.../jukebox-keyboard.py --watch`. Selects the board by the
  `Jukebox Keyboard` USB product string. Install with
  `software/jukebox-keyboard/deploy.sh install`.
- `software/storage/` — **not a package**: `raid-music.sh`, an on-host helper to
  create/adopt the RAID 1 music library on the two HDDs and mount it at `/media`
  (Volumio's `USB` source), including the JMS583 UAS quirk. Idempotent; refuses
  to reformat a non-empty disk without `--reformat`. See its README.
- `deploy-all.sh` (repo root) — install/uninstall/verify/status for all packages
  in dependency order.
- This skill lives in `skills/jukebox/`.

When the user asks for jukebox work and anything looks different from this
file, trust the live box: `jukebox-audio.sh status` + `verify` +
`/var/log/jukebox-audio.log` tell the real story for audio, and
`software/storage/raid-music.sh status` (`cat /proc/mdstat`) for the disks.

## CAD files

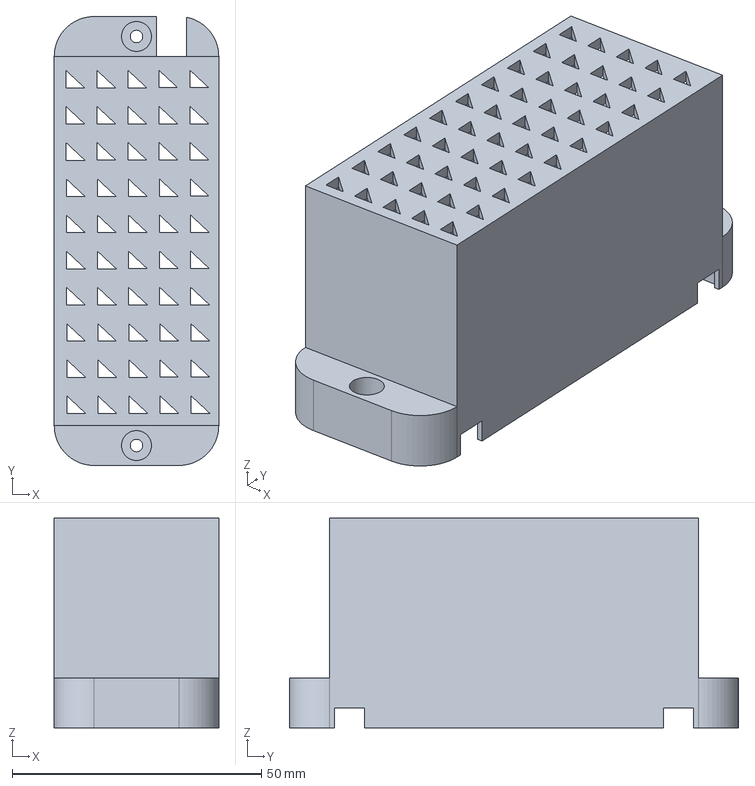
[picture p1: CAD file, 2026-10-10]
hardware/3d-models/Electronic support/KeyboardController.FCStd
33.0 x 90.0 x 42.0 mm

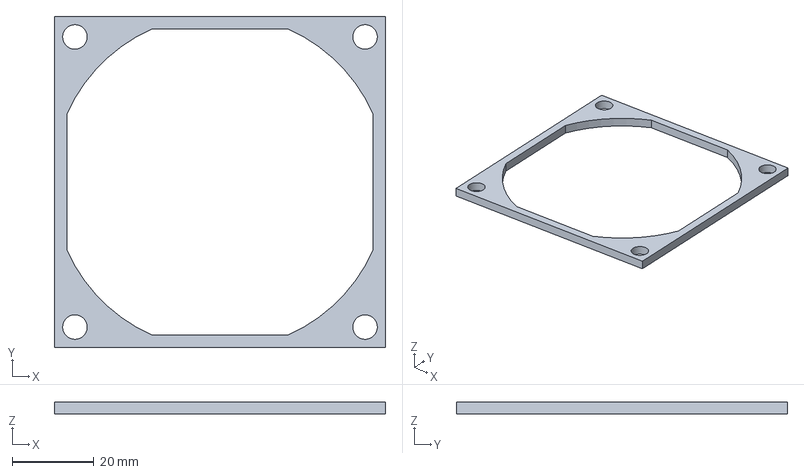
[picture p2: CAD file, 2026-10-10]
hardware/3d-models/hdd/FanPlate.FCStd
81.0 x 81.0 x 3.00 mm

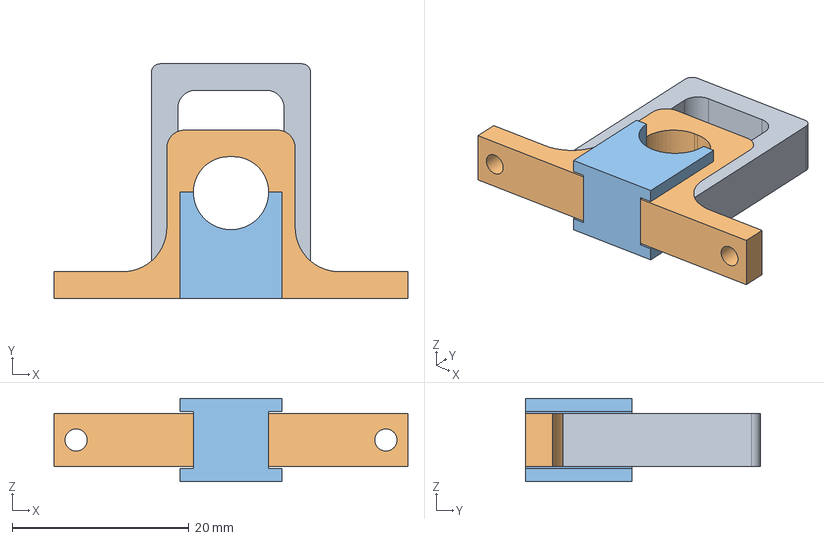
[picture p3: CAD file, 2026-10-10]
hardware/3d-models/Pi support/UsbSoundCardFixer.FCStd
40.0 x 26.5 x 9.40 mm
UsbSoundCardBodyFixer
UsbSoundCardCableFixer
UsbSoundCardCableInside

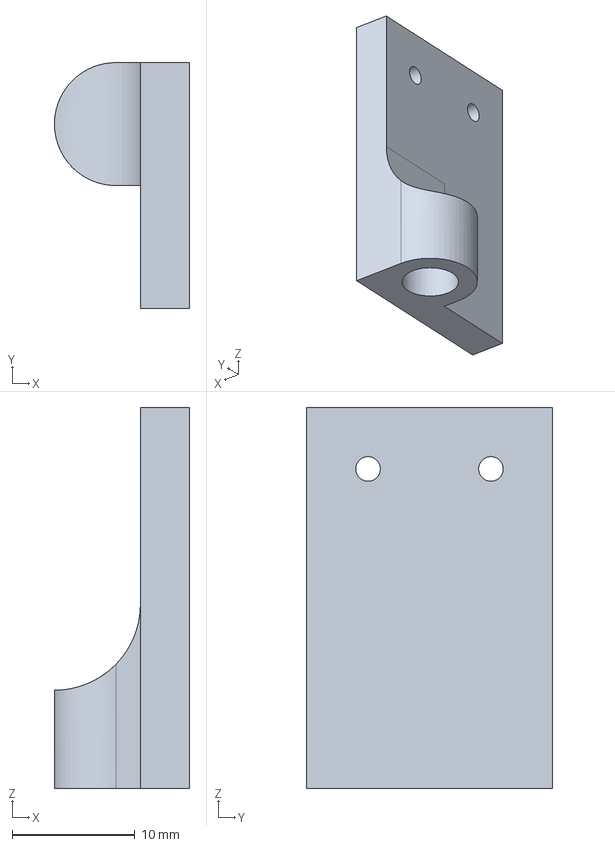
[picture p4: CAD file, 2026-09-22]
hardware/3d-models/screen/screenSupportBottomLeft.FCStd
11.0 x 20.0 x 31.0 mm

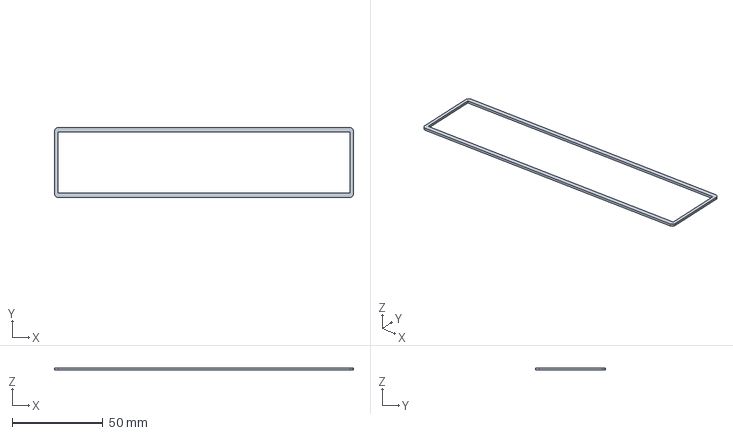
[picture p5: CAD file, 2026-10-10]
hardware/3d-models/Spectrum/externalFrame.FCStd
165.0 x 38.5 x 1.20 mm

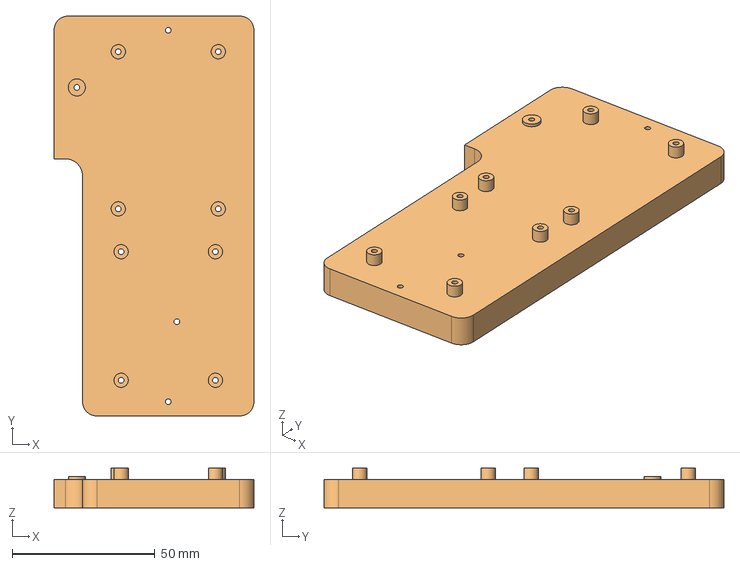
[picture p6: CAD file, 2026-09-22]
hardware/3d-models/Electronic support/PowerAndPotsControllerBox.FCStd
70.0 x 140.0 x 14.0 mm
Base

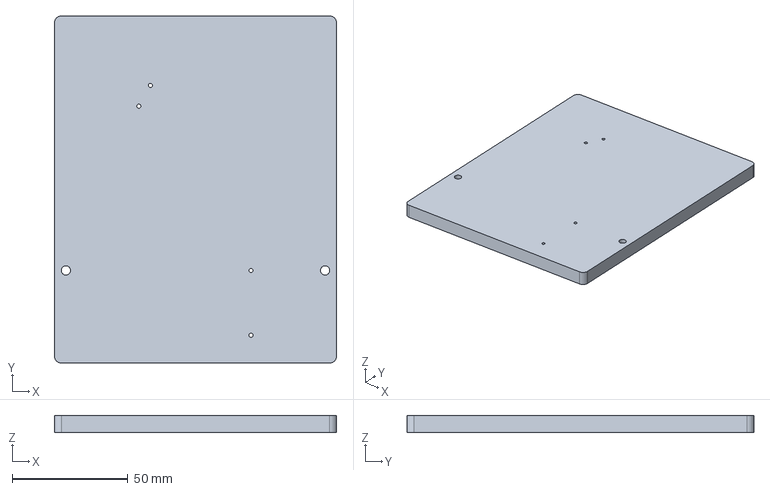
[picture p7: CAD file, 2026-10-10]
hardware/3d-models/hdd/HddFloor.FCStd
122.0 x 150.0 x 7.50 mm

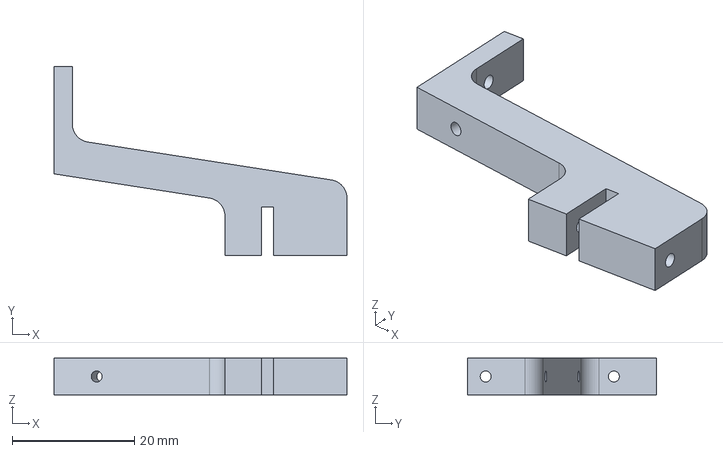
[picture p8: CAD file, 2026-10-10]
hardware/3d-models/Pi support/hatsFixer.FCStd
48.0 x 31.0 x 6.00 mm

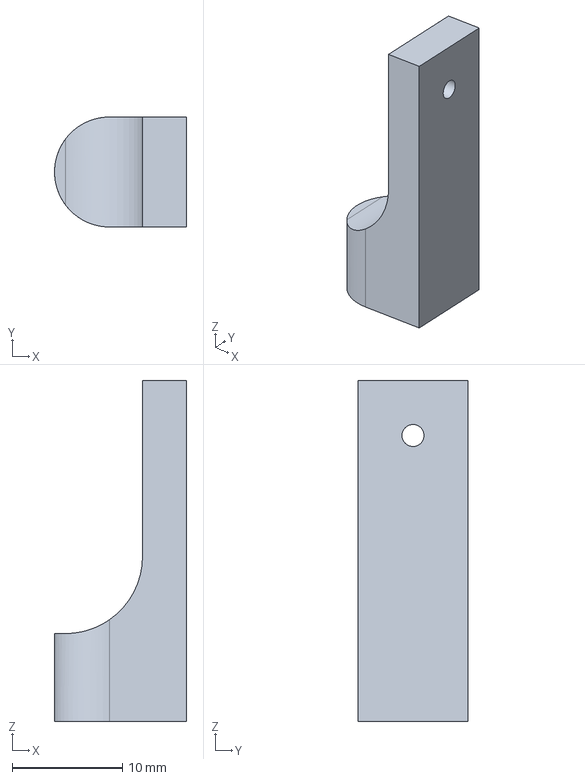
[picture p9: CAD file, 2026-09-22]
hardware/3d-models/screen/screenSupportTopLeft.FCStd
12.0 x 10.0 x 31.0 mm

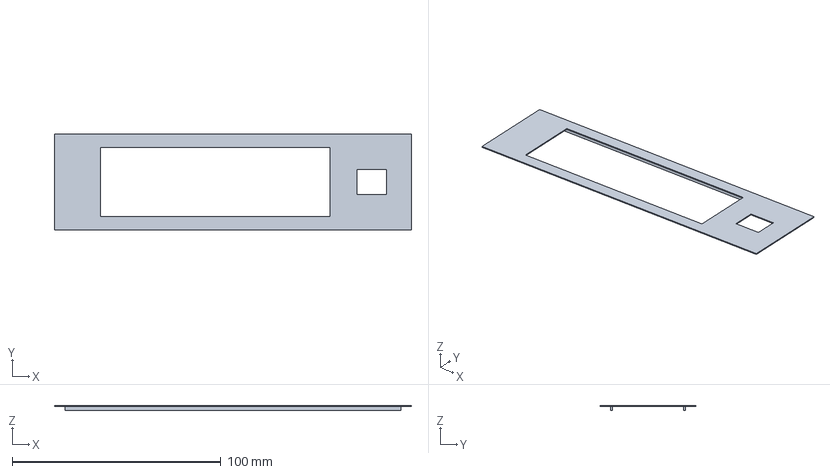
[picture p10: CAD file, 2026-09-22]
hardware/3d-models/Spectrum/frame.FCStd
171.0 x 46.0 x 2.30 mm

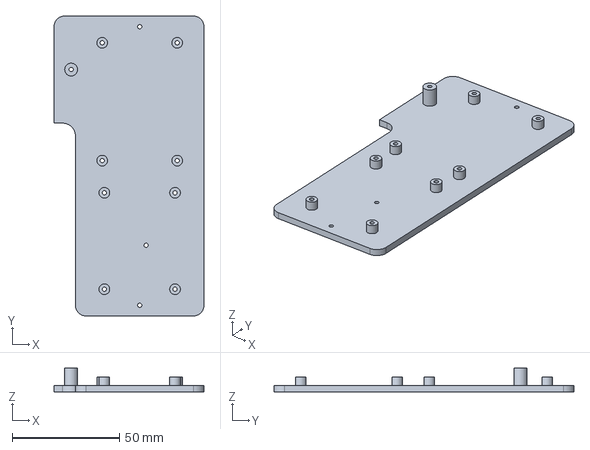
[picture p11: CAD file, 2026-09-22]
hardware/3d-models/Electronic support/PowerAndPotsController.FCStd
70.0 x 140.0 x 11.0 mm

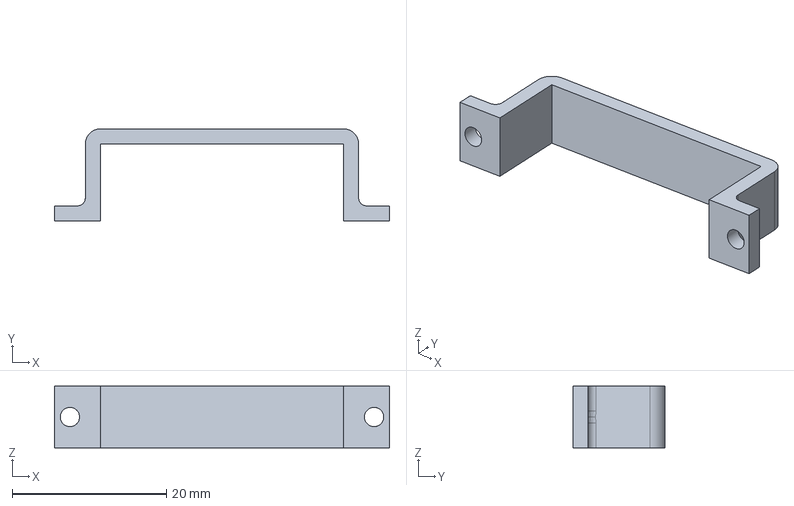
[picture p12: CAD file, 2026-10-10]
hardware/3d-models/hdd/HddCover.FCStd
43.5 x 12.0 x 8.00 mm

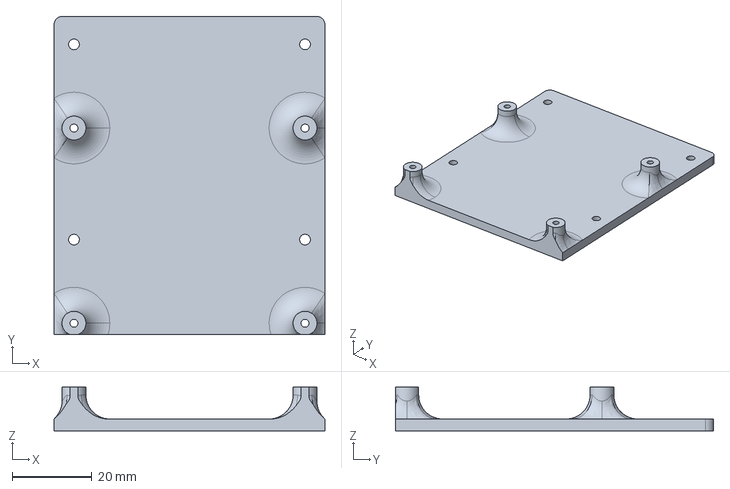
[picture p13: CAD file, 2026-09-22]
hardware/3d-models/Pi support/PiSupportShifter.FCStd
68.0 x 79.8 x 11.0 mm

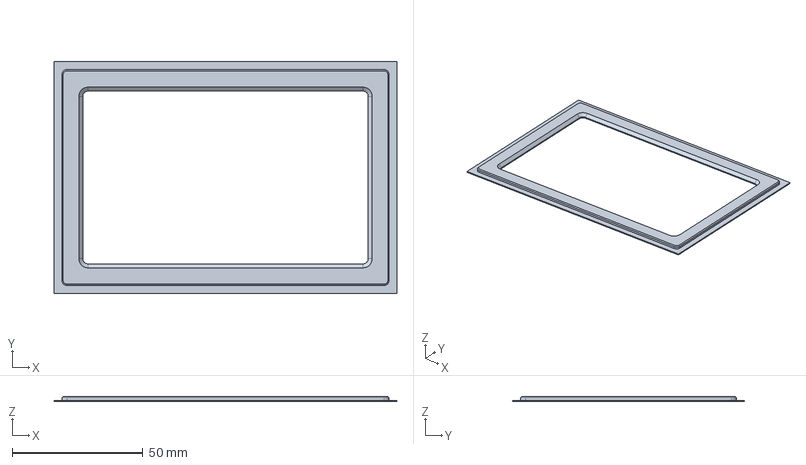
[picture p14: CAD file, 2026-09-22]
hardware/3d-models/screen/screenCover.FCStd
131.0 x 88.5 x 2.00 mm

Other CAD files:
hardware/3d-models/Electronic support/FuseCase.FCStd
hardware/3d-models/hdd/HddSupportWall.FCStd
hardware/3d-models/Pi support/PiSupport.FCStd
hardware/3d-models/screen/screenSupportBottomRight.FCStd
hardware/3d-models/screen/screenJoint.FCStd
hardware/3d-models/screen/screenSupport.FCStd
hardware/3d-models/screen/screenSupportTopRight.FCStd

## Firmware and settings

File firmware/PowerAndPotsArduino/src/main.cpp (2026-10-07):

#include <Arduino.h>
#include "power-state-machine.hpp"

const byte POT_SINGLE_PIN = A3;
const byte POT_SINGLE_POWER_PIN = 15;

const byte POW_TRISTATE_PIN = A2;
const byte POT_VOLUME_PIN = A1;

const byte POWER_SW_PIN = 14;

const byte MUX_ANALOG_PIN = A0;
const byte MUX_SELECT_PIN = 7;

const byte MUX_SELECT2_PIN = 5;

const byte MULTI_PUSH_SWITCH_PIN = 4;

const byte ROTARY_SWITCH_1_PIN = 8;
const byte ROTARY_SWITCH_2_PIN = 9;

struct PotPoint {
  int raw;
  int value;
};

const PotPoint POT_VOLUME_POINTS[] = {
  {547, 20},
  {878, 10},
  {978, 5},
  {1018, 2},
  {1023, 0},
};

const PotPoint POT_SINGLE_POINTS[] = {
  {0, 0},
  {1023, 20},
};

const PotPoint POT_BALANCE_POINTS[] = {
  {0, 20},
  {1023, 0},
};

const PotPoint POT_MULTI_SECOND_POINTS[] = {
  {0, 20},
  {318, 10},
  {533, 0},
};

// Spare pot on mux channel X2. Placeholder linear calibration (edit to match
// the real pot, like the other tables).
const PotPoint POT_AUX_POINTS[] = {
  {0, 0},
  {1023, 20},
};

const byte NUM_SAMPLES = 10;

int readAveraged(byte pin) {
  long sum = 0;
  for (byte i = 0; i < NUM_SAMPLES; i++) {
    sum += analogRead(pin);
  }
  return sum / NUM_SAMPLES;
}

bool readDigitalStable(byte pin) {
  byte highCount = 0;
  for (byte i = 0; i < NUM_SAMPLES; i++) {
    if (digitalRead(pin)) highCount++;
    delay(1);
  }
  return highCount > NUM_SAMPLES / 2;
}

template<byte N>
int scalePot(int reading, const PotPoint (&points)[N]) {
  if (reading <= points[0].raw) return points[0].value;
  for (byte i = 1; i < N; i++) {
    if (reading <= points[i].raw) {
      long span = points[i].raw - points[i - 1].raw;
      long num = (long)(reading - points[i - 1].raw) * (points[i].value - points[i - 1].value);
      return points[i - 1].value + (int)((num + (num >= 0 ? span / 2 : -span / 2)) / span);
    }
  }
  return points[N - 1].value;
}

const unsigned long REPORT_INTERVAL_MS = 250;
const int NEVER = -9999;

struct ReportedValue {
  int value = NEVER;
  unsigned long lastMs = -REPORT_INTERVAL_MS;
};

bool throttleReport(ReportedValue &v, int reading, int threshold) {
  if ((v.value == NEVER || abs(reading - v.value) > threshold) &&
      millis() - v.lastMs >= REPORT_INTERVAL_MS) {
    v.value = reading;
    v.lastMs = millis();
    return true;
  }
  return false;
}

void report(const char *name, int value) {
  Serial.print(name);
  Serial.println(value);
}

void report(const char *name, const char *value) {
  Serial.print(name);
  Serial.println(value);
}

void reportPot(const char *name, int value, int raw) {
  Serial.print(name);
  Serial.print(value);
  Serial.print(" (raw ");
  Serial.print(raw);
  Serial.println(")");
}

ReportedValue potVolume, potSingle, potBalance, potMultiSecond, potAux, powTristate, powSw, multiPush, rotary;

void setup() {
  Serial.begin(9600);

  pinMode(POWER_SW_PIN, INPUT);
  pinMode(MULTI_PUSH_SWITCH_PIN, INPUT_PULLUP);
  pinMode(ROTARY_SWITCH_1_PIN, INPUT_PULLUP);
  pinMode(ROTARY_SWITCH_2_PIN, INPUT_PULLUP);

  pinMode(POT_SINGLE_POWER_PIN, OUTPUT);
  digitalWrite(POT_SINGLE_POWER_PIN, LOW);

  pinMode(MUX_SELECT_PIN, OUTPUT);
  pinMode(MUX_SELECT2_PIN, OUTPUT);

  setupPower();
}

void loop() {
  // Serial input from the host (jukebox-pots): a "POWER: ..." command is
  // handled, anything else asks for a full status report. The report request
  // marks every value as "never reported" so the next checks re-emit them all
  // even though they have not changed (used right after the host opens the
  // port, to seed volume/balance from the current pots).
  static char cmdBuf[32];
  static byte cmdLen = 0;
  while (Serial.available() > 0) {
    char c = Serial.read();
    if (c == '\n' || c == '\r') {
      if (cmdLen > 0 && strncmp(cmdBuf, "POWER:", 6) == 0) {
        cmdBuf[cmdLen] = '\0';
        handlePowerCommand(cmdBuf);
      } else {
        potVolume.value = NEVER;
        potSingle.value = NEVER;
        potBalance.value = NEVER;
        potMultiSecond.value = NEVER;
        potAux.value = NEVER;
        powTristate.value = NEVER;
        powSw.value = NEVER;
        multiPush.value = NEVER;
        rotary.value = NEVER;
      }
      cmdLen = 0;
    } else if (cmdLen < sizeof(cmdBuf) - 1) {
      cmdBuf[cmdLen++] = c;
    }
  }

  servicePowerOff();

  digitalWrite(POT_SINGLE_POWER_PIN, HIGH);

  delayMicroseconds(300);

  int potSingleRaw = readAveraged(POT_SINGLE_PIN);
  int potSingleReading = scalePot(potSingleRaw, POT_SINGLE_POINTS);

  int powTristateRaw = readAveraged(POW_TRISTATE_PIN);
  int powTristateState = powTristateRaw > 500 ? 2 : powTristateRaw > 100 ? 1 : 0;
  bool powSwReading = readDigitalStable(POWER_SW_PIN);
  handlePowerSwitch(powSwReading);

  int potVolumeRaw = readAveraged(POT_VOLUME_PIN);
  int potVolumeReading = scalePot(potVolumeRaw, POT_VOLUME_POINTS);

  // Mux channels: A = MUX_SELECT_PIN, B = MUX_SELECT2_PIN (C tied to GND).
  //   A=0 B=0 -> X0: multi second pot
  //   A=1 B=0 -> X1: balance pot
  //   A=0 B=1 -> X2: aux pot
  digitalWrite(MUX_SELECT_PIN, LOW);
  digitalWrite(MUX_SELECT2_PIN, LOW);
  delayMicroseconds(50);
  int multiSecondPotRaw = readAveraged(MUX_ANALOG_PIN);
  int multiSecondPotReading = scalePot(multiSecondPotRaw, POT_MULTI_SECOND_POINTS);
  delayMicroseconds(50);
  digitalWrite(MUX_SELECT_PIN, HIGH);
  int balancePotRaw = readAveraged(MUX_ANALOG_PIN);
  int balancePotReading = scalePot(balancePotRaw, POT_BALANCE_POINTS);
  delayMicroseconds(50);
  digitalWrite(MUX_SELECT_PIN, LOW);
  digitalWrite(MUX_SELECT2_PIN, HIGH);
  delayMicroseconds(50);
  int auxPotRaw = readAveraged(MUX_ANALOG_PIN);
  int auxPotReading = scalePot(auxPotRaw, POT_AUX_POINTS);

  bool multiPushSwitch = readDigitalStable(MULTI_PUSH_SWITCH_PIN);
  bool rotarySwitch1 = readDigitalStable(ROTARY_SWITCH_1_PIN);
  bool rotarySwitch2 = readDigitalStable(ROTARY_SWITCH_2_PIN);

  digitalWrite(POT_SINGLE_POWER_PIN, LOW);

  int rotaryState = !rotarySwitch1 ? 1 : (!rotarySwitch2 ? 2 : 0);

  bool reported = false;

  if (throttleReport(potVolume, potVolumeReading, 0)) {
    reportPot("POT volume: ", potVolume.value, potVolumeRaw);
    reported = true;
  }

  if (throttleReport(potSingle, potSingleReading, 0)) {
    reportPot("POT single: ", potSingle.value, potSingleRaw);
    reported = true;
  }

  if (throttleReport(potBalance, balancePotReading, 0)) {
    reportPot("POT balance: ", potBalance.value, balancePotRaw);
    reported = true;
  }

  if (throttleReport(potMultiSecond, multiSecondPotReading, 0)) {
    reportPot("POT multi second: ", potMultiSecond.value, multiSecondPotRaw);
    reported = true;
  }

  if (throttleReport(potAux, auxPotReading, 0)) {
    reportPot("POT aux: ", potAux.value, auxPotRaw);
    reported = true;
  }

  if (throttleReport(powTristate, powTristateState, 0)) {
    report("POWER tristate: ", powTristate.value == 2 ? "RIGHT" : powTristate.value == 1 ? "LEFT" : "CENTER");
    reported = true;
  }

  if (throttleReport(powSw, powSwReading ? 1 : 0, 0)) {
    report("POWER switch: ", powSw.value ? "ON" : "OFF");
    reported = true;
  }

  if (throttleReport(multiPush, multiPushSwitch ? 1 : 0, 0)) {
    report("MULTI PUSH switch: ", multiPush.value ? "OFF" : "ON");
    reported = true;
  }

  if (throttleReport(rotary, rotaryState, 0)) {
    report("MULTI ROTARY switch: ", rotary.value == 1 ? "SW1" : rotary.value == 2 ? "SW2" : "OFF");
    reported = true;
  }

  if (reported) {
    Serial.println("-----------------------------------------");
  }

  delay(100);
}

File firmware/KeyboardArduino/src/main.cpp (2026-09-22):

#include <Arduino.h>

const uint8_t ROW_PINS[4] = {2, 3, 4, 5};
const uint8_t COL_PINS[4] = {6, 7, 8, 9};
const unsigned long DEBOUNCE_MS = 20;
const unsigned long LONG_PRESS_MS = 1000;
const unsigned long REPEAT_MS = 500;

struct KeyState {
  bool pressed;
  unsigned long lastChange;
  unsigned long downTime;
  unsigned long lastRepeat;
};

KeyState keys[4][4] = {};

void emit(const __FlashStringHelper *evt, uint8_t r, uint8_t c) {
  Serial.print(evt);
  Serial.print(' ');
  Serial.print(r + 1);
  Serial.print(' ');
  Serial.println(c + 1);
}

void setup() {
  Serial.begin(9600);
  for (uint8_t r = 0; r < 4; r++) {
    pinMode(ROW_PINS[r], OUTPUT);
    digitalWrite(ROW_PINS[r], HIGH);
  }
  for (uint8_t c = 0; c < 4; c++) pinMode(COL_PINS[c], INPUT_PULLUP);
}

void loop() {
  unsigned long now = millis();
  for (uint8_t r = 0; r < 4; r++) {
    for (uint8_t i = 0; i < 4; i++) digitalWrite(ROW_PINS[i], HIGH);
    digitalWrite(ROW_PINS[r], LOW);
    delayMicroseconds(10);
    for (uint8_t c = 0; c < 4; c++) {
      KeyState &k = keys[r][c];
      bool raw = digitalRead(COL_PINS[c]) == LOW;
      if (raw != k.pressed && now - k.lastChange >= DEBOUNCE_MS) {
        k.pressed = raw;
        k.lastChange = now;
        if (raw) {
          k.downTime = now;
          k.lastRepeat = now;
          emit(F("DOWN"), r, c);
        } else {
          emit(F("UP"), r, c);
          emit(now - k.downTime < LONG_PRESS_MS ? F("PRESS") : F("LONG_PRESS"), r, c);
        }
      } else if (k.pressed && now - k.lastRepeat >= REPEAT_MS) {
        k.lastRepeat = now;
        emit(F("PRESSED"), r, c);
      }
    }
  }
}

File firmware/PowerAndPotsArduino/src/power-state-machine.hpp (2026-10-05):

#pragma once

#include <Arduino.h>

const byte RELAY_PIN = 2;
const byte RELAY_ON = LOW;
const byte RELAY_OFF = HIGH;
const unsigned long POWER_LONG_PRESS_MS = 5000;

// Delay between a "POWER: off" command from the host and the relay cut.
// The host (the Pi) is gone by then, but this board keeps running from 5VSB,
// so it is the only side that can wait: the daemon sends the message just
// before it shuts the Pi down, this timer lets the Pi finish halting, and the
// relay is cut afterwards. A number in the command ("POWER: off 45") overrides
// it, so the delay can be tuned from the host without reflashing.
const unsigned long POWER_OFF_DELAY_MS = 30000;

bool powerOn = false;
bool prevPowerSw = false;
bool longPressFired = false;
unsigned long powerSwPressMs = 0;

// A relay cut armed by the host, cut when millis() reaches relayOffAtMs.
bool relayOffPending = false;
unsigned long relayOffAtMs = 0;

void setupPower() {
  pinMode(RELAY_PIN, OUTPUT);
  digitalWrite(RELAY_PIN, RELAY_OFF);
}

void cutRelay() {
  powerOn = false;
  digitalWrite(RELAY_PIN, RELAY_OFF);
}

// Accepts the host's power line. "POWER: off" arms a delayed relay cut after
// POWER_OFF_DELAY_MS; "POWER: off N" waits N seconds instead (N may be 0 for
// an immediate cut); "POWER: cancel" disarms a pending cut (used if the host
// could not actually shut itself down). Anything else is ignored.
void handlePowerCommand(const char *line) {
  if (strncmp(line, "POWER: cancel", 13) == 0) {
    if (relayOffPending) {
      relayOffPending = false;
      Serial.println("POWER: off cancelled");
    }
    return;
  }
  if (strncmp(line, "POWER: off", 10) != 0) return;
  unsigned long delayMs = POWER_OFF_DELAY_MS;
  const char *p = line + 10;
  while (*p == ' ') p++;
  if (*p >= '0' && *p <= '9') {
    delayMs = strtoul(p, NULL, 10) * 1000UL;
  }
  relayOffPending = true;
  relayOffAtMs = millis() + delayMs;
  Serial.print("POWER: off in ");
  Serial.print(delayMs / 1000UL);
  Serial.println("s");
}

// Called every loop; performs the armed relay cut when its time arrives.
void servicePowerOff() {
  if (relayOffPending && (long)(millis() - relayOffAtMs) >= 0) {
    relayOffPending = false;
    Serial.println("POWER: hard off");
    cutRelay();
  }
}

void handlePowerSwitch(bool pressed) {
  if (pressed && !prevPowerSw) {
    powerSwPressMs = millis();
    longPressFired = false;
  } else if (pressed && powerOn && !longPressFired &&
             millis() - powerSwPressMs >= POWER_LONG_PRESS_MS) {
    longPressFired = true;
    if (relayOffPending) {
      relayOffPending = false;
      Serial.println("POWER: off cancelled");
    }
    Serial.println("POWER: hard off");
    cutRelay();
  } else if (!pressed && prevPowerSw && !longPressFired) {
    if (!powerOn) {
      powerOn = true;
      Serial.println("POWER: ON");
      digitalWrite(RELAY_PIN, RELAY_ON);
    } else {
      Serial.println("POWER: soft off");
    }
  }
  prevPowerSw = pressed;
}

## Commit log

2026-09-22 some 3d printing models
    [FuseCase.FCStd, HddSupportWall.FCStd, PiSupport.FCStd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]
2026-09-30 Add dual audio output support for Volumio on Raspberry Pi
    - Introduced a new feature that allows simultaneous audio output to both the I2S DAC (volume-controlled) and the 3.5 mm jack (constant level).
    - Created README.md to document installation, usage, and configuration details.
    - Implemented deploy.sh script for easy installation and remote execution on Volumio host.
    - Developed jukebox-audio.sh script to manage the audio output configuration, including installation, verification, and uninstallation processes.
    - Added systemd units to ensure configuration persistence across Volumio restarts.
    - Included various helper functions for managing ALSA configurations and state.
2026-10-01 Add jukebox operations skill
    Documents how to connect to the jukebox (Volumio on Raspberry Pi),
    what to expect there, the dual audio output setup, common tasks and
    troubleshooting.
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2026-10-01 Add jukebox-ui boost: fix sluggish Volumio touch UI
    The DSI touch UI was slow to scroll because of four measured causes on the
    Pi 4, all re-applied/guarded by software/volumio-ui-boost/:
    - Chromium launched with --disable-gpu-compositing --disable-3d-apis, forcing
    software compositing (scroll CPU 55% -> 22% of one core without them)
    - --force-renderer-accessibility added by Debian/RPi chromium.d
    - now_playing client CSS used a full-screen 50px background blur plus 20-30px
    screen filters (scroll CPU 40% -> 11% with lighter blur)
    - a phantom HDMI-1 output forced the X screen to 848x480 over the 800x480 DSI
    panel (right ~48px clipped, touch mapping ~6% off); turned off in-session
    Adds a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
2026-10-01 jukebox-audio: fixed analyser low-shelf bass trim (60 Hz, -6.02 dB)
    The spectrum analyser over-reads deep bass by hardware design. Add a fixed
    low-shelf filter on the ANALYSER BRANCH ONLY, so the speakers are untouched:
    volumio -> ... -> jukeboxSplit (multi)
    |- volumioSoftVol (softvol) -> ... -> I2S DAC
    '- jukeboxEq (trim) -> jukeboxEqDsp (equal) -> USB/HDMI/jack
    Implemented with the CAPS Eq4p LADSPA plugin hosted by the alsaequal 'equal'
    ALSA plugin (packages caps + libasound2-plugin-equal, auto-installed; apt on a
    Volumio box is often mid-upgrade, so a dpkg .deb fallback is included).
    Defaults: 60 Hz corner, -6.02 dB (= half amplitude), Q 0.5.
    Measured on the live ALSA cha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
2026-10-01 jukebox-pots: drive DAC volume/balance from the PowerAndPots Arduino
    Add software/jukebox-pots: an always-on service that reads POT volume and
    POT balance from the PowerAndPots Arduino over USB serial (9600 baud) and
    maps them onto the I2S DAC software volume. Volume goes through the Volumio
    API (stays in sync); balance writes SoftMaster per-channel. Only the DAC
    branch is touched - the analyser feed carries no SoftMaster and is never
    modified.
    - jukebox-pots.py: dependency-free daemon (termios; no pyserial), rescan on
    unplug/replug, --probe and --selftest. Deliberately does NOT assert DTR:
    on the Micro DTR is tied to reset and would reset the power state machine.
    - install.sh: idempote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
2026-10-01 jukebox-pots: request a full status report on connect (seed at boot)
    The firmware only reports a value when it changes, so a board already
    running (powered from 5VSB) when the Pi boots would stay silent and the
    daemon would never learn the current pot positions.
    - firmware: any byte received on the serial port marks every reported value
    as 'never' so the next checks re-emit them all once.
    - daemon: write a newline right after opening the port; --probe does it too.
    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
2026-10-01 jukebox-audio: add CamillaDSP tone control (bass/treble) on the DAC branch
    Adds a live bass/treble tone control to the speaker path, driven by two more
    pots of the PowerAndPots Arduino.
    Audio chain (DAC branch only; analyser untouched):
    volumioSoftVol (SoftMaster) -> jukeboxTone (cdsp -> CamillaDSP shelves) -> DAC
    jukeboxEq (analyser trim) -> USB/HDMI/jack
    - jukebox-audio.sh: renders a CamillaDSP config per variant (Lowshelf +
    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
2026-10-01 jukebox-audio: rebuild /etc/mpd.conf when missing (fresh-install recovery)
    On a box where /etc/mpd.conf is absent (fresh install, cleanup, failed
    update) MPD never starts, so nothing plays and the guard cannot fix it.
    ensure_mpd_conf() rebuilds it from Volumio's own template with the current
    settings (device 'volumio', mixer_type none, buffer/period times) and runs
    on both install and apply.
2026-10-02 jukebox-audio: make cdsp active-config writes ownership-proof
    The cdsp plugin opened the active CamillaDSP config with fopen(..., "w"),
    truncating it in place. Any chain open as root (install/verify) left the
    file root:0644, so the next playback as the unprivileged MPD user could
    not rewrite it and died after ~1 s with:
    Error writing output config file /var/lib/jukebox-audio/camilla-active.usb.yml
    Failed to open "alsa" ... snd_pcm_hw_params() failed: No such device
    Plugin fix: render to a sibling temp file, chmod 0666 and rename it over
    the destination (rename only needs write permission on the 0777
    directory), so whoever owned the file before no longer matters. Rebuilt
    the shipped arm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
    [libasound_module_pcm_cdsp.c]
2026-10-02 cdsp: conceal application underruns instead of killing playback
    Playback died after a few minutes with "failed to open output device":
    MPD stalled briefly (slow SD card / system load), the plugin drained its
    ring, declared a fatal XRUN and MPD closed the output, taking ~75 s to
    recover by itself.
    - plugin: when the ring stays empty past a period, feed one period of
    silence down the CamillaDSP pipe and keep waiting; never raise the fatal
    XRUN to the player. The silence buffer is allocated once in hw_params
    and freed on close. Rebuilt the shipped armhf .so.
    - jukebox-audio.sh: MPD buffer_time 200 ms -> 3 s (period stays 50 ms) so
    ordinary stalls never even reach the plugin.
    - README/S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
    [libasound_module_pcm_cdsp.c]
2026-10-02 moode: implement dual output + tone/balance/volume (M1-M6)
    New software/moode/dual-output package (moOde 10, aarch64):
    - jukebox-moode.sh: split moOde's _audioout into a CamillaDSP DAC branch
    (tone + balance + volume) and a fixed-level USB analyser branch, with
    DAC-only fail-safe when the analyser card is absent; guard unit
    re-asserts the split if moOde rewrites its config.
    - moode-sync.php: regenerate /etc/mpd.conf via moOde's own updMpdConf()
    with mixer_type null (CamillaDSP fader) and a 3 s ALSA buffer.
    - cdsp/: patched plugin source (underrun concealment + atomic config
    write) built natively on the Pi (aarch64).
    - tone config jukebox-tone.yml; volume type CamillaDSP; balance as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
    [libasound_module_pcm_cdsp.c]
2026-10-05 jukebox-pots: identify the Arduino by USB product string, not by port
    The box now has two identical Arduino Micros (PowerAndPots + Keyboard):
    same VID:PID 2341:8037 and no unique USB serial, so the kernel cannot tell
    them apart and the daemon sometimes grabbed the keyboard board (observed
    connecting to the wrong ttyACM).
    Give each board its own USB product string in firmware and select the pots
    board by that string:
    * firmware/*/platformio.ini: board_build.usb_product = "Jukebox Pots" /
    "Jukebox Keyboard" (USB-level identity, no commands to the devices).
    * jukebox-pots.py: find_port() matches the product string via /dev/serial/by-id
    or the sysfs "product" attribute; drop the VID:PID/by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
2026-10-05 jukebox-audio: don't fail the playback test on an empty queue
    verify --with-playback ran `mpc play` and, when the queue was empty (typical
    after a reboot), reported "MPD playback test failed" even though the audio
    chain was fine. Now:
    * if the queue is empty, add a track from the library for the test and clear it
    afterwards (restoring the empty queue);
    * if the library is empty too, warn and skip the test instead of failing;
    * if the queue already has tracks, use them and change nothing.
    Bump to v1.2.2.
2026-10-05 jukebox-audio: give MPD 20 s after boot before the playback test
    Right after boot MPD is still starting (database not loaded, first output not
    open), so verify --with-playback could fail for a reason that is not the audio
    chain. When nothing is playing, wait 20 s before testing; keep the empty-queue
    handling (add a library track, or skip with a distinct "skipped" result rather
    than reporting a failure). Bump to v1.2.4.
    Also bump pot-overlay to v1.5.0 (range sent by the daemon).
2026-10-05 jukebox-keyboard: playback keys from the KeyboardArduino
    New package that turns the keyboard board's 4x4 button matrix into transport
    controls. A daemon reads the board's key events over USB serial (DOWN/UP/PRESS/
    LONG_PRESS/PRESSED) and, on key press, runs the mapped Volumio command:
    play, pause, stop, previous track, next track.
    * jukebox-keyboard.py: termios serial reader; selects the board by the
    "Jukebox Keyboard" USB product string (never by port, like jukebox-pots);
    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
2026-10-05 jukebox-keyboard: add mute key
    New MUTE action: on key press it reads the current mute state from Volumio and
    runs volume=mute or volume=unmute accordingly (Volumio exposes mute through the
    volume command, and its own "toggle" is not reliable). Assign with
    --key-action mute ROW,COL; bump to v1.1.0. Docs updated.
2026-10-05 ui-nav: separate UI navigation from pot-overlay
    Keeping responsibilities apart: pot-overlay goes back to only carrying pot
    values, and screen navigation moves to its own package.
    * software/volumio/ui-nav/: stdlib HTTP/SSE server (port 3211) + injected
    ui-nav.js that drives the UI's ui-router $state; POST {"type":"nav",
    "view":"toggle"|"home"|"queue"} switches the screen. install/deploy/README,
    guard to re-inject after Volumio rewrites the UI pages.
    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
2026-10-05 keyboard: favourite key, run through the UI (ui-nav)
    Add a FAVOURITE action to jukebox-keyboard; it asks the UI to do the toggle
    (via ui-nav) instead of emitting on its own socket connection, so the heart
    and the toast react.
    This surfaced a Volumio backend gap for webradio: its checkFavourites() only
    looks at the music favourites list, so the heart never lights for a radio and
    its add never toggles (the native touch heart has the same problem). ui-nav.js
    now handles radios itself: decide add/remove from radio-favourites (server's
    /favourite query), save the station name (state.artist), and sync the heart by
    hooking the same "urifavourites" event the UI uses. Music keeps the native path.
    *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
2026-10-05 jukebox-keyboard: add clear-queue key
    New CLEAR action mapped to Volumio's clearQueue command (same as the UI's queue
    button), emptying the play queue. Assign with --key-action clear ROW,COL; bump
    to v1.5.0. Docs updated.
2026-10-05 keyboard: add save-queue-as-playlist key
    New SAVEQUEUE action: saves the current queue as a playlist, auto-named
    "Playlist N". The name comes from a new ui-nav endpoint (/next-playlist-name,
    based on the playlists in /data/playlist) and the save is emitted through the
    UI's own socket (saveQueueToPlaylist), the same call the UI makes.
    * jukebox-keyboard: SAVEQUEUE action; bump to v1.6.0.
    * ui-nav: savequeue UI action + /next-playlist-name; bump to v1.3.0.
    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
2026-10-05 refactor: finish the files/ split for dual-output and ui-boost; add deploy-all
    Complete the refactor started in fcce98c for the two remaining packages:
    * dual-output: move the engine, the precompiled binaries (camilladsp, cdsp
    plugin) and cdsp/ source under files/; extract the systemd guard units and
    the udev rule there (install_units installs them, with the old inline
    generation as fallback); add uninstall.sh; fix deploy.sh to ship files/ with
    scp -r (the cdsp/ subdir broke the non-recursive copy).
    * ui-boost: move the helper and guard units under files/; rewrite install.sh
    and deploy.sh to the uniform layout and add uninstall.sh.
    * keyboard: the key map is now versioned in fil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
    [libasound_module_pcm_cdsp.c]
2026-10-05 power: short press halts the Pi, relay cut by the Arduino after it is down
    Firmware (PowerAndPotsArduino):
    - accept host commands on the serial line: "POWER: off [N]" arms a delayed
    relay cut (POWER_OFF_DELAY_MS, default 30 s) and "POWER: cancel" disarms it;
    any other line keeps the old full status-report behaviour.
    - service the armed cut in the loop; a long press still cuts immediately and
    cancels a pending soft-off.
    jukebox-pots daemon:
    - on "POWER: soft off" (power button short press) send "POWER: off <delay>" to
    the Arduino (which keeps running from 5VSB) and then power the Pi off, so the
    relay is cut only after the Pi has finished halting. On by default; disable
    with --no-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
    [main.cpp, power-state-machine.hpp]
2026-10-07 pots: aux volume pot (ceiling x aux) on a second mux channel
    Add a third pot on the PowerAndPots board's CD4051B mux (channel X2,
    addressed with B on D5; D7 stays A). The firmware reads and reports it
    as "POT aux" and includes it in the full status report.
    jukebox-pots now multiplies it with the volume pot: the volume pot sets
    the system ceiling (0-100%) and the aux scales below it, so the value
    sent to Volumio is volume_pot * (aux / 20), reaching silence at aux 0.
    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
2026-10-10 storage: add RAID 1 music-library setup script and docs
    Two 3.5" HDDs in USB enclosures, mirrored and mounted at /media (Volumio's
    USB source). software/storage/raid-music.sh is an on-host, idempotent
    create-or-adopt helper (never reformats a non-empty disk without --reformat;
    adopts an existing array untouched) that also pins the usb-storage.quirks
    workaround for the unreliable JMicron JMS583 UAS bridges. Documented in
    software/storage/README.md and the root README (incl. the power caveat and
    the SMB music workflow).
2026-10-10 skill: document the RAID music library and USB storage quirks
    Add the two mirrored HDDs to the expected-state checklist, a Disks / RAID
    section (raid-music.sh create/adopt + verify/apply/status), the power and
    JMS583/UAS traps in the golden rules, and troubleshooting rows for a
    degraded array or a missing /media mount. Also point the SMB music
    workflow and the repo map at software/storage/.
2026-10-10 Adding new hardware 3d models
    [FanPlate.FCStd, HddCover.FCStd, HddFloor.FCStd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]
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
